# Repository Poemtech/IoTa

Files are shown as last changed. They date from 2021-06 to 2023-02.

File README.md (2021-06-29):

# IoTa
### The IoTa is an open-source cellular developer board featuring the ublox SARA-R410 modem, an ARM Cortex-M0+ and an ARM Cortex-M4.
### IoTa: a complete cellular IoT hardware development platform
### *Features:*
- [NXP ARM Cortex-M0+](https://www.nxp.com/products/processors-and-microcontrollers/arm-microcontrollers/general-purpose-mcus/kl-series-cortex-m0-plus/kinetis-kl1x-48-mhz-mainstream-small-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)
- [NXP ARM Cortex-M4](https://www.nxp.com/products/processors-and-microcontrollers/arm-microcontrollers/general-purpose-mcus/k-series-cortex-m4/k2x-usb/kinetis-k22-120-mhz-cost-effective-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)
- Battery fuel gauge
- LiPo charge control
- LEDs
  -  White
  -  RGB
- 3.3V Power output
- Four Serial Interfaces
  - 2 UART's
  - 1 CAN
  - 1 SPI (with a second optional configuration)
  - 1 I2C (with a second optional configuration)
- 23 GPIO pins
- 19 PWC/DAC channels
- 8 ADC channels
- 10 Wakeup Pins
 ### Efficient Development with the Arduino IDE 
Dual processor design eliminates the need for a host processor. Code development on the user processor using the Arduino IDE enables rapid deployment of your IoT design. 

oshw_facts (1)

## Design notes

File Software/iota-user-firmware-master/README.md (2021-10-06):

# POEM Technology IoTa Arduino Integration
Files necessary to add POEM Technology IoTa board to the Arduino IDE

Needs Arduino IDE version 1.8.0 and up.

## Installation
To set up the Arduino IDE environment for working with the POEM Technology IoTa board, add
https://poemtechnology.com/downloads/iota/arduino_integration/package_iota_index.json
to your Arduino IDE board manager.

## For more information
Example Arduino sketches are available in the [libraries directory](konektdash/libraries)
There are also more example sketches at: https://github.com/hologram-io/hologram-dash-arduino-examples

Questions? Ask a question at: mailto: support@poemtechnology.com

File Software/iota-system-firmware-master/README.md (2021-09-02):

# IoTa System Arduino Core

## Introduction
This is an Arduino implementation for the System processor on the POEM Technology IoTa.
Build your own image using the Arduino IDE or build the included POEM Technology
firmware.

## Arduino Installation

1. Find your local Arduino directory (e.g. macos `~/Documents/Arduino/`).
2. In the `hardware` directory, clone this repository.
3. Open the Arduino IDE (close/reopen if already running).
4. Select the `IoTa System` board from the `system.poemtechnology.com IoTa Boards` section of the board selection menu.

## Building Firmware

1. With the `IoTa System` board selected, from the Examples menu, select an example sketch.
2. Click the Verify button to build.

## Programming the User processor

1. Use Hologram Arduino package version 0.10.4 or later.
2. Open the user sketch to program.
3. From the Programmer select `hologram.io USB loader`.
4. From the Firmware Updates menu, select `Custom Firmware`.
5. Click the Upload button in the Arduino IDE.

## Programming the System processor

1. From the Programmer select `system.poemtechnology.com USB`.
2. Connect the IoTa to your computer via USB.
3. Press the Program button on the IoTa.
4. Click the Upload button in the Arduino IDE.

## Support
Please feel free to [reach out to us](mailto:support@poemtechnology.com) if you have any questions/concerns.

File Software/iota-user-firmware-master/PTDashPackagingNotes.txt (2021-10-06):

Follow the guidance on this page: https://www.hackster.io/wallarug/arduino-ide-creating-custom-boards-89f7a6

Note: To get IIS to serve up JSON, do this: https://blogs.msdn.microsoft.com/africaapps/2013/06/07/how-to-serve-static-json-files-from-a-windows-azure-website/

https://myilevel.com/downloads/dash/arduino_integration//package_poemtechnology_index.json

https://myilevel.com/downloads/dash/arduino_integration/ptdash-0.11.2.zip

Get a SHA256 has of the ZIP file: (Get-FileHash ZIP filename -Algorithm SHA 256).Hash

Get the size of the ZIP file: (Get-Item ZIP).Length

Create Package
--------------
To create a package, run the Create-ArduinoPackage.ps1 -Version <version> from Powershell. Change to the directory
where Create-ArduinoPackage.ps1 is before running as the path defaults are based off of that location.

Deploy Package
--------------
Package hosting on corp site can be managed via SiteGround by copying the contents of the "arduino_integration" folder to the corp site folder
under "/poemtechnology.com/public_html/downloads/iota/arduino_integration".

The contents of the ZIP file are the files/folders below the ptdash directory:
	/cores
	/libraries
	/variants
	boards.txt
	platform.txt
	programmers.txt

Changed VM compiler settings to remove deep search for libraries.

To work on the PT Dash library at the same time as using another verison of the library, create a TFS/VS workspace in
the Arduino documents directory (e.g. C:\Users\<usernmae>\Documents\Arduino\hardware\ptdash-user-firmware-working) and
get and work in that directory. Note: Be sure to select the correct PT Dash version (i.e. look for your working forlder)
before bulding a test harness. Also, the name matters. Make sure it starts with the boards name.

There are name collisions between boards that have the same name. So, The POEM Technology Dash is called the "ptdash" and
the working (i.e. development) version is called "ptdashdev". This mainly impacts the boards.txt file and requires that any
item with the name "ptdashdev" needs to be renamed to "ptdash" as part of the packaging process. Also, a working version of
the PTDash board needs to be installed in order for the programmers to be found by the development environment (as of 
2020-02-10).

PS replacement magic for baords.txt: PS> Get-Content boards.txt | Select-String ptdashdev | % { $_.Line.replace("dev", "").replace("DEV", "").replace("Dev", "") }

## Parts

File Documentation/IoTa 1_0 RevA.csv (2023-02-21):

Comment | Description | Designator | Footprint | LibRef | Quantity | MFG | MPN
ANT-A-1JB | Amphenol | ANT_UFL | UFL | ANT-A-1JB | 1 | Amphenol | A-1JB
1 uF | Capacitor, 1 uF, 0603 | C1 | CAP0603 | CAP1uF_0603 | 1 | MURATA | GRM188R71C105KA12D
0.1 uF | CAPACITOR, 0.1 uF, 0402 | C2, C3, C4, C6, C7, C8, C9, C12, C14, C15, C18, C24, C25, C26, C48 | CAP0402 | CAP0.1uF_0402 | 15 | MURATA | GRM155R61C104KA88D
2.2 uF | Capacitor, 2.2 uF, 0603 | C10, C11, C13, C28 | CAP0603 | CAP2.2uF_0603 | 4 | SAMSUNG | CL10A225MQ8NNNC
1uF | CAPACITOR, 1uF, 0402 | C16, C20, C49 | CAP0402 | CAP1uF_0402 | 3 | AVX | 04026D105KAT2A
10 nF | CAPACITOR, 10 nF, 0402 | C27, C39 | CAP0402 | CAP10nF_0402 | 2 | MURATA | GRM155R71C103KA01D
10 uF | Capacitor, 10 uF, 0603 | C33, C34 | CAP0603 | CAP10uF_0603 | 2 | Murata | GRM188R60J106ME84D
22 uF | Capacitor, 22 uF, 0603 | C36, C37, C38 | CAP0603 | CAP22uF_0603 | 3 | MURATA | GRM188R60J226MEA0D
56 pf | CAPACITOR, 56 pF, 0402 | C40 | CAP0402 | CAP56pF_0402 | 1 | KEMET | C0402C560J5GACTU
47 pF | CAPACITOR, 47 pF, 0402 | C41, C42, C43, C44, C45 | CAP0402 | CAP47pf_0402 | 5 | AVX | 04025A470JAT2A
15 pf | CAPACITOR, 15 pF, 0402 | C46 | CAP0402 | CAP15pF_0402 | 1 | AVX/ELCO | 04025A150JAT2A
330uF | Capacitor, 330 uF, 1210, Polarized Tantalum | C47 | CAP1210POL | CAP330uF_1210P | 1 | AVX | F950J337MBAAQ2
LED_0402_VLMW | LED, Vishay White 0402 | D1, D7 | LED_0402_VISHAY_VLMW | LED_0402_VLMW | 2 | VISHAY | VLMW1500-GS08
 | DIODE,ZENER VOLTAGE SUPPRESSOR,+/-14V | D3, D4, D5, D6, D9, D10, D11 | PESD_0402 | PESD_14V | 7 | Littlefuse | PESD0402-140
CDBQR0230L | Schottky Barrier Diode, 200 mA, 30 V, 0402 package | D8 | DIODE_0402 | DIODE_0402_200mA | 1 | Comchip | CDBQR0230L
3A | Fuse, 3A, 0603 | F6 | RES0603 | FUSE_0603 | 1 | Bourns | SF-0603S300-2
Micro USB B FCI 10118193 | Connector, Micro USB B, FCI | J1 | USB_MICRO_FCI_10118193 | USB_MICRO_B_FCI_10118193 | 1 | Amphenol FCI | 10118193-0001LF
BAT_TERM_TOP_ENTRY | Battery Connector JST-PH2 Top Entry | J20 | JST-PH-2-Top | BAT_TERM_TOP_ENTRY | 1 | JST | B2B-PH-SM4-TB(LF)(SN)
22-28-4180 | Header, Male, 1x18, 0.1" | JLEFT, JRIGHT | 1X18 | PINHD-1X18 | 2 | MOLEX | 22-28-4180
FerriteBead_220ohm | FerriteBead, 220ohm | L1, L2, L3, L7 | RES0603 | FerriteBead_220ohm | 4 | Murata | BLM18AG121SN1D
1uH | Inductor, 1 uH, Coilcraft | L5 | COILCRAFT_XFL4020 | INDUCTOR_1UH_XFL4020-102MEC | 1 | Coilcraft | XFL4020-102MEC
22 | Resistor, 22 ohm, 0402 case, 1% | R1, R2 | RES0402 | RES22R_0402 | 2 | YAEGO | RC0402FR-0722RL
62k | Resistor, 62K ohm, 0402 case | R7 | RES0402 | RES62K_0402_1 | 1 | YAEGO | RC0402FR-0762KL
2k | Resistor, 2K ohm, 0402 case | R8 | RES0402 | RES2K_0402 | 1 | YAEGO | RC0402FR-072KL
150k | Res, 150k ohm, 0402 case, 1% | R12 | RES0402 | RES150K_0402 | 1 | YAEGO | RC0402FR-07150KL
1M | Resistor, 1M ohm, 0402 case, 1% | R13 | RES0402 | RES1M_0402 | 1 | YAEGO | RC0402FR-071ML
470 | Resistor, 470 ohm, 0402 case, 1% | R19, R20 | RES0402 | RES470R_0402 | 2 | PANASONIC | ERJ-2GEJ471X
120 | Resistor, 120 ohm, 0402 case, 1% | R21 | RES0402 | RES120R_0402 | 1 | PANASONIC | ERJ-2GEJ121X
160 | Resistor, 160 ohm, 0402 case, 1% | R22 | RES0402 | RES160R_0402 | 1 | PANASONIC | ERJ-2GEJ161X
10K | Resistor, 10k ohm, 0402 | R24, R35, R36, R37, R38, R40, R47, R2000 | RES0402 | RES10K_0402 | 8 | YAEGO | RC0402JR-0710KL
75 | Resistor, 75 ohm, 0402, 1% | R26, R65 | RES0402 | RES75R_0402 | 2 | YAEGO | RC0402FR-0775RL
1k | Resistor, 1k, 0402 case, 1% | R45 | RES0402 | RES1K_0402 | 1 | YAEGO | RC0402JR-071KL
CRCW08050000Z0EA |  | R51 | RESC2013X50X30LL20T20 | CMP-2001-04896-1 | 1
0 | Resistor, 0 ohm, 0402 | R66 | RES0402 | RES0R_0402 | 1 | PANASONIC | ERJ-2GE0R00X
SIM_CARD_NANO | Connector, SIM Card,Nano | SIM1 | SIM_CARD_NANO | SIM_CARD_NANO | 1 | GLOBAL CONNECTOR TECHNOLOGY | SIM8050-6-0-14-01-A
LED_RGB_1mm_sq | LED, Tri-color, RGB, 1mm sq | smlp | LED-RGB-1X1 | LED_RGB_1mm_sq | 1 | Rohm | SMLP34RGB1W3
SWITCH_PTS810 | Switch, C&K, PTS810 | SW1, SW2 | SWITCH_PTS810 | SWITCH_PTS810 | 2 | C&K Components | PTS810 SJM 250 SMTR LFS
MICROCHIP_73871 | Stand-alone Load Sharing and LiPo Battery Charge management controller | U1 | QFN50P400X400X80_20_pin | MICROCHIP_73871 | 1 | MICROCHIP | MCP73871-2CCI/ML
TPS63020 | Regulator, Boost Buck, Adjustable, 3A | U2 | QFN-14-POWERPAD3X4DSJ | TPS63020 | 1 | TI | TPS63020DSJ
CDBQR0230L | Schottky Barrier Diode, 1.5 A, 30 V, 0402 package | U3, U4 | SODFL350X99-2N | DIODE_SOD123F_1A | 2 | Toshiba Semiconductor and Storage | CRS08(TE85L,Q,M)
MK22FN1M0VLH12 | ARM® Cortex®-M4 Kinetis K20 Microcontroller IC 32-Bit 120MHz 1MB (1M x 8) FLASH 64-LQFP (10x10) | U5 | LQFP-64N | MK22FN1M0VLH12 | 1 | Freescale | MK22FN1M0AVLH12
FREESCALE_MKL17Z256VFM4 | Microprocessor, Freescale, MKL17Z256VFM4 | U6 | QFN50P50 | FREESCALE_MKL17Z256VFM4 | 1 | FREESCALE | MKL17Z256VFM4
VOLTAGE_TRANSLATOR_4_BIT | IC, Voltage Translator, 4-bit | U8 | UQFN_16 | VOLTAGE_TRANSLATOR_4_BIT | 1 | TI | SN74AVC4T774RSVR
 | IC, Current-limited Load Switch, Active High | U9 | SC70-5 | TPS22945 | 1 | Texas Instruments | TPS22945DCKR
 | IC Regulator, LDO 3.3V 0.5A, 4XDFN | U10 | REG_NCP160AMX180TBG | NCP177-D | 1 | On Semi | NCP177AMX330TCG
SARA-R410 | LTE module for multi-regional use; Cat M1/NB1 deployed bands: 1*, 2, 3, 4, 5, 8, 12, 13, 18, 19, 20, 25, 26*, 28 (* roaming bands) | U16 | SARA | SARA-R410M-02B | 1 | U-BLOX | SARA-R410M-02B
MAX1704X | MAX17043/MAX17044: Battery Fuel Guage (43 is 1cell, 44 is 2cell) | U19 | TDFN-8 | MAX1704X | 1 | Maxim | MAX17043G+U
CRYSTAL_16MHz | Crystal SMD, 16 MHz | X1 | CRYSTAL-SMD-2X1.6 | CRYSTAL_16MHz | 1 | AVX | CX2016DB16000D0WZRC1
32.768 kHz | 32.768kHz ±20ppm Crystal 12.5pF 90 kOhm -40°C ~ 85°C Surface Mount 2-SMD | X2, X3 | CRYSTAL_ABS05 | CRYSTAL_32.768K_ABS05 | 2 | Abracon | ABS05-32.768KHZ-T

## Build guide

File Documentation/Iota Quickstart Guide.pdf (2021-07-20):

# POEM IoTa Quickstart Guide

## Instructions for Running Serial Port Commands

## (NOTE: This document is derived from the documentation for the Hologram DASH. References to the DASH as a module as now replaced by IoTa, but software names will still contain

the legacy “dash” nomenclature. (e.g. “dash_repl_basic”).

### Contents

I. SIM Card Management
-Inserting SIM Card
-Creating a Hologram Account -Activating SIM Card
II. | IoTa Setup
III. | REPL Program -Installing the Arduino IDE -Uploading dash_repl_basic -Connecting the IoTa
IV. | Commands -Cloud Connect -LED -Clock
V. Messages

I. SIM Card Management

Inserting SIM Card:

To properly insert your SIM card, pop it out of the carrier card and insert it into the back of the IoTa in the small silver compartment that is the same size as the SIM. There is a small image of the SIM card next to the compartment that details the orientation it should be inserted.

Orienting SIM Card:

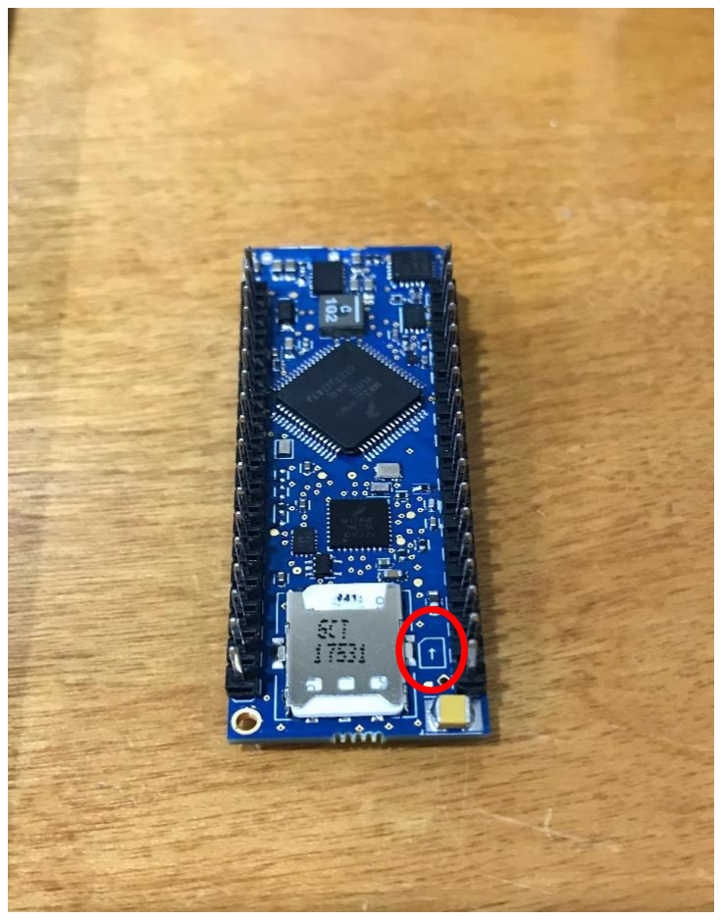
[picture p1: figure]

Creating a Hologram Account:

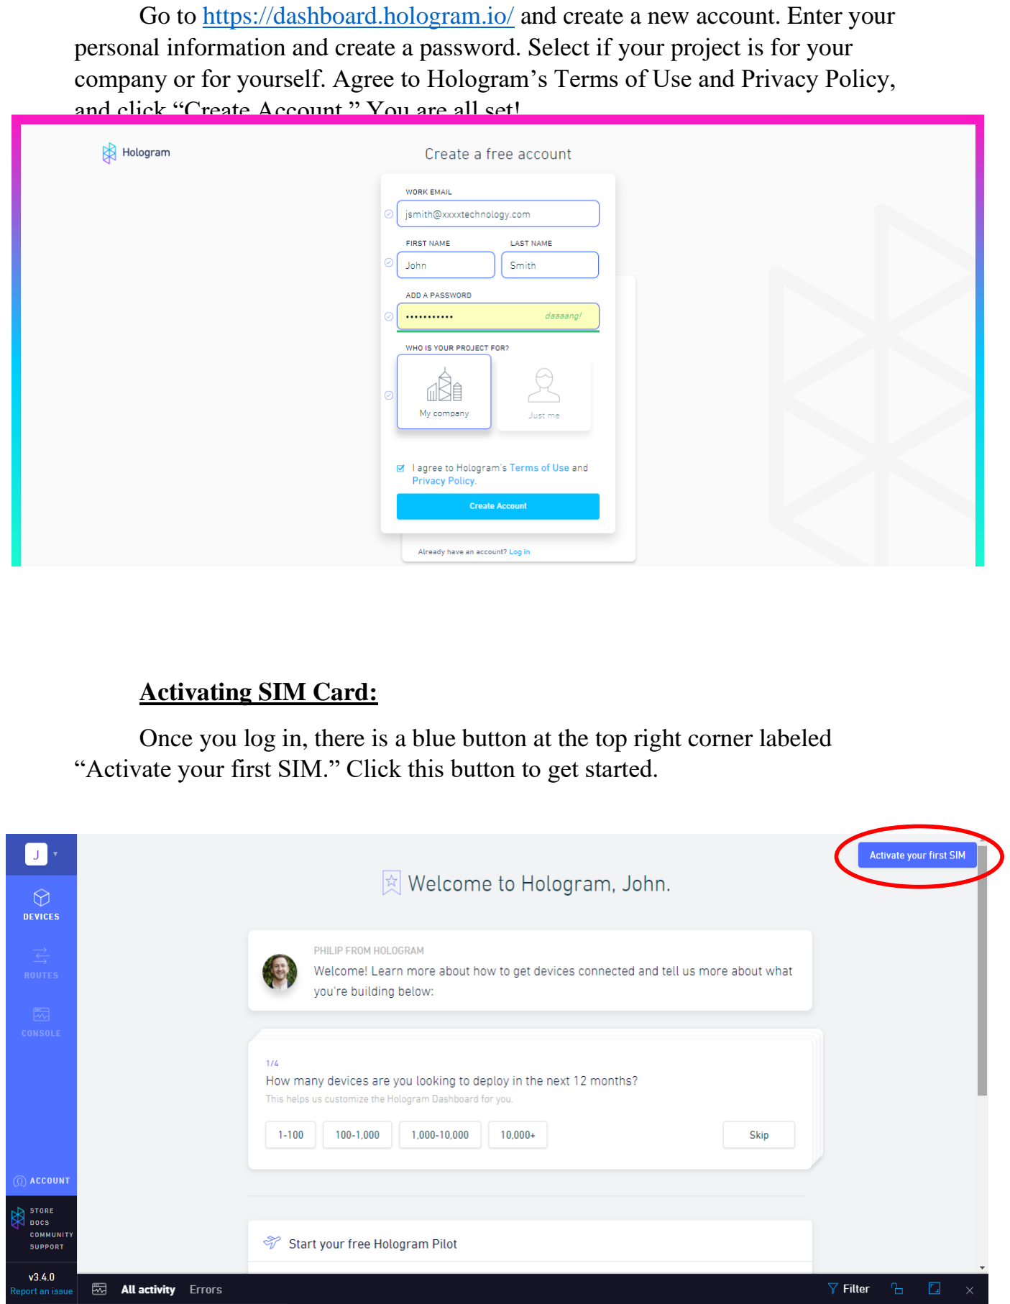
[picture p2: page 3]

Go to https://dashboard.hologram.io/ and create a new account. Enter your personal information and create a password. Select if your project is for your company or for yourself. Agree to Hologram’s Terms of Use and Privacy Policy, and click “Create Account.” You are all set!

Activating SIM Card:

Once you log in, there is a blue button at the top right corner labeled “Activate your first SIM.” Click this button to get started.

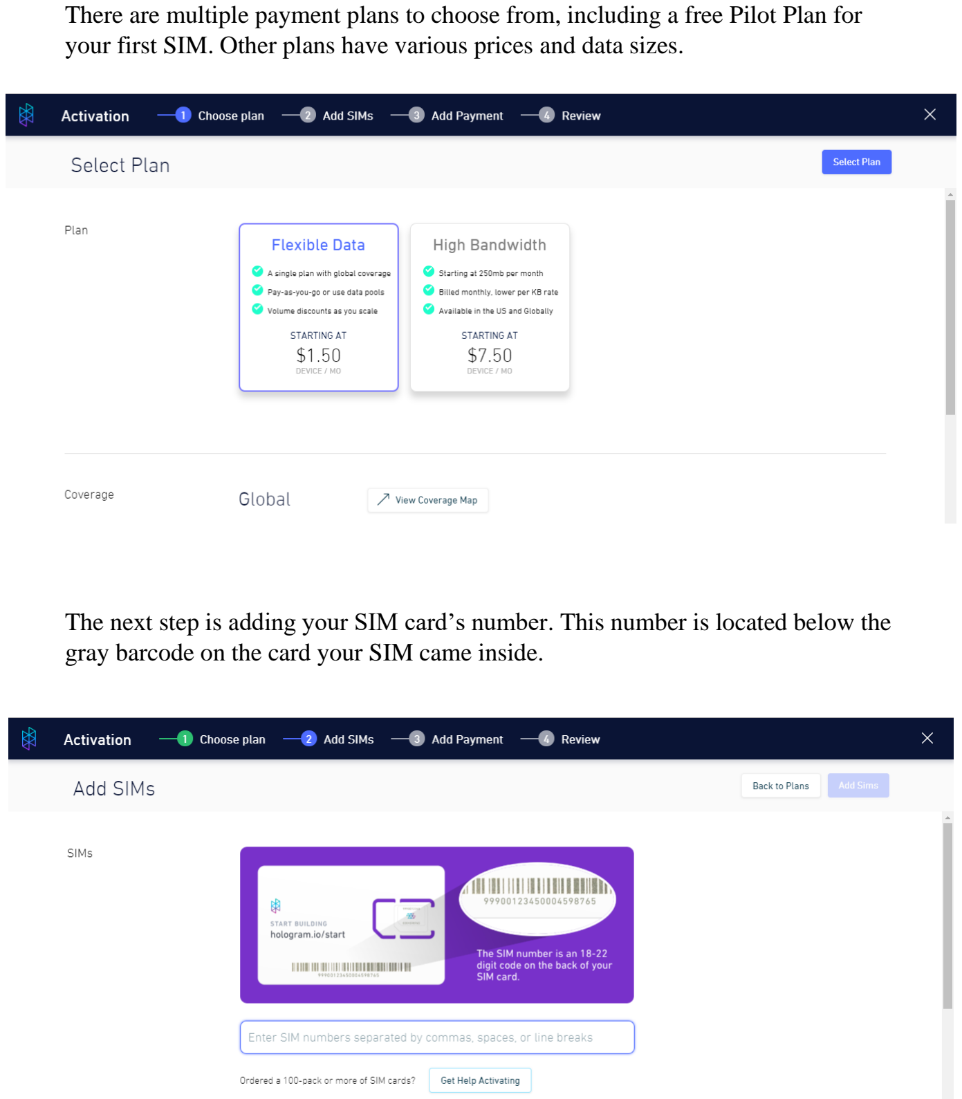
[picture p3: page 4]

There are multiple payment plans to choose from, including a free Pilot Plan for your first SIM. Other plans have various prices and data sizes.

The next step is adding your SIM card’s number. This number is located below the gray barcode on the card your SIM came inside.

You have the option of customizing your SIM’s name, or giving it a tag for future reference.

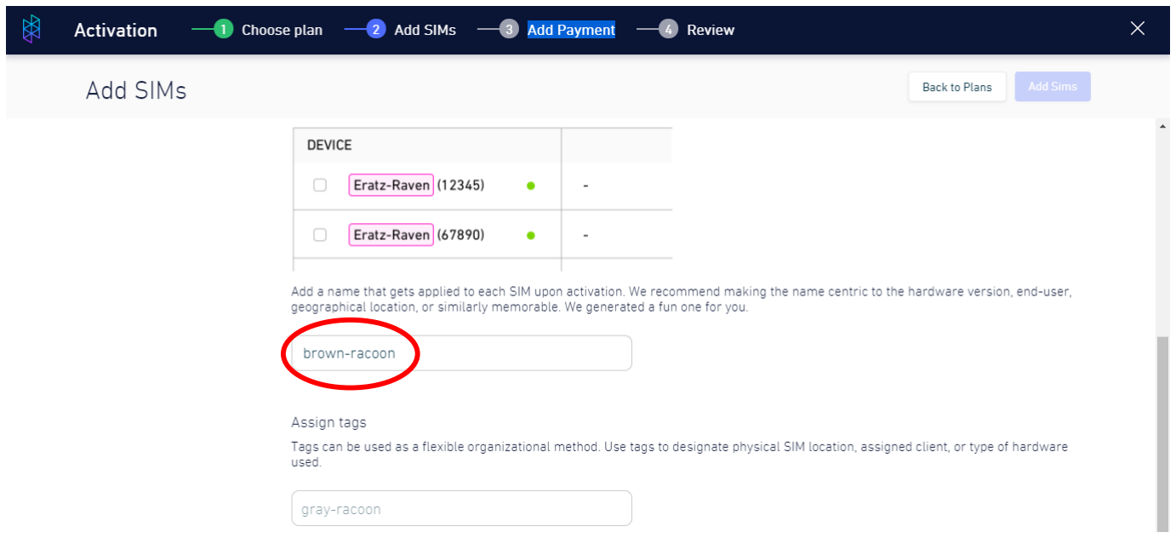
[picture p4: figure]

Enter your payment info. You can review your information before confirming your order. Congrats! You have activated your first SIM card.

II. | IoTa Setup
| Plug the supplied USB cable onto the IoTa and then into a port on your computer.

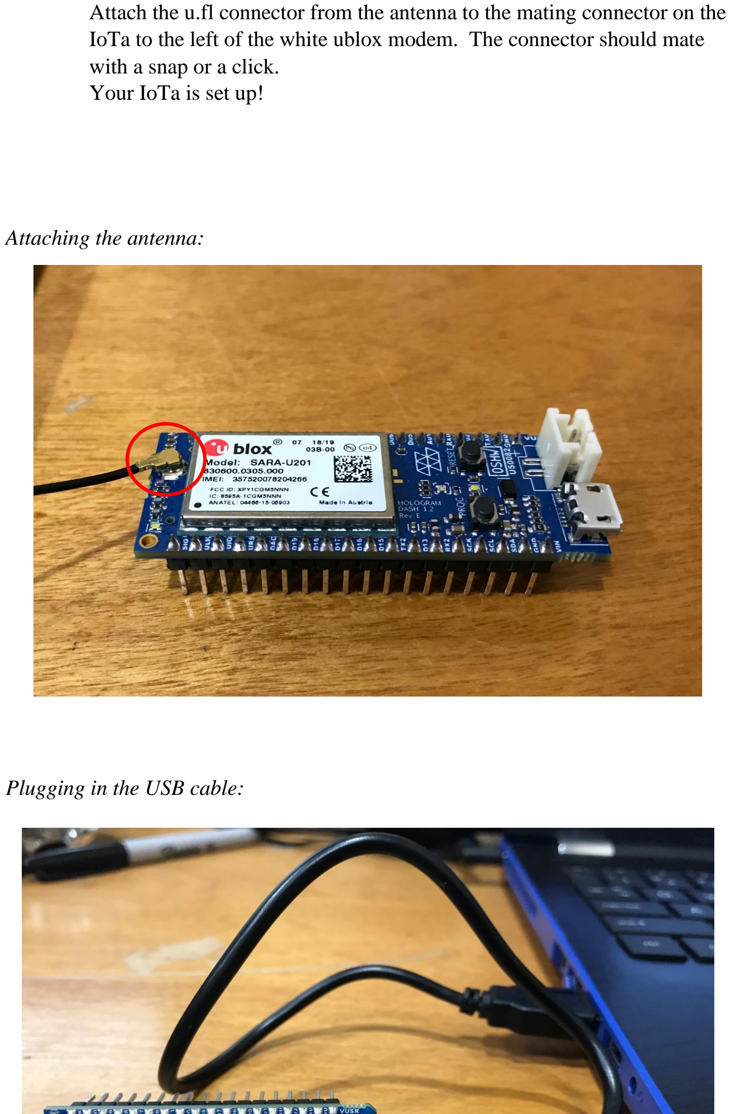
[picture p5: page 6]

Attach the u.fl connector from the antenna to the mating connector on the IoTa to the left of the white ublox modem. The connector should mate with a snap or a click.
Your IoTa is set up!

Attaching the antenna:

Plugging in the USB cable:

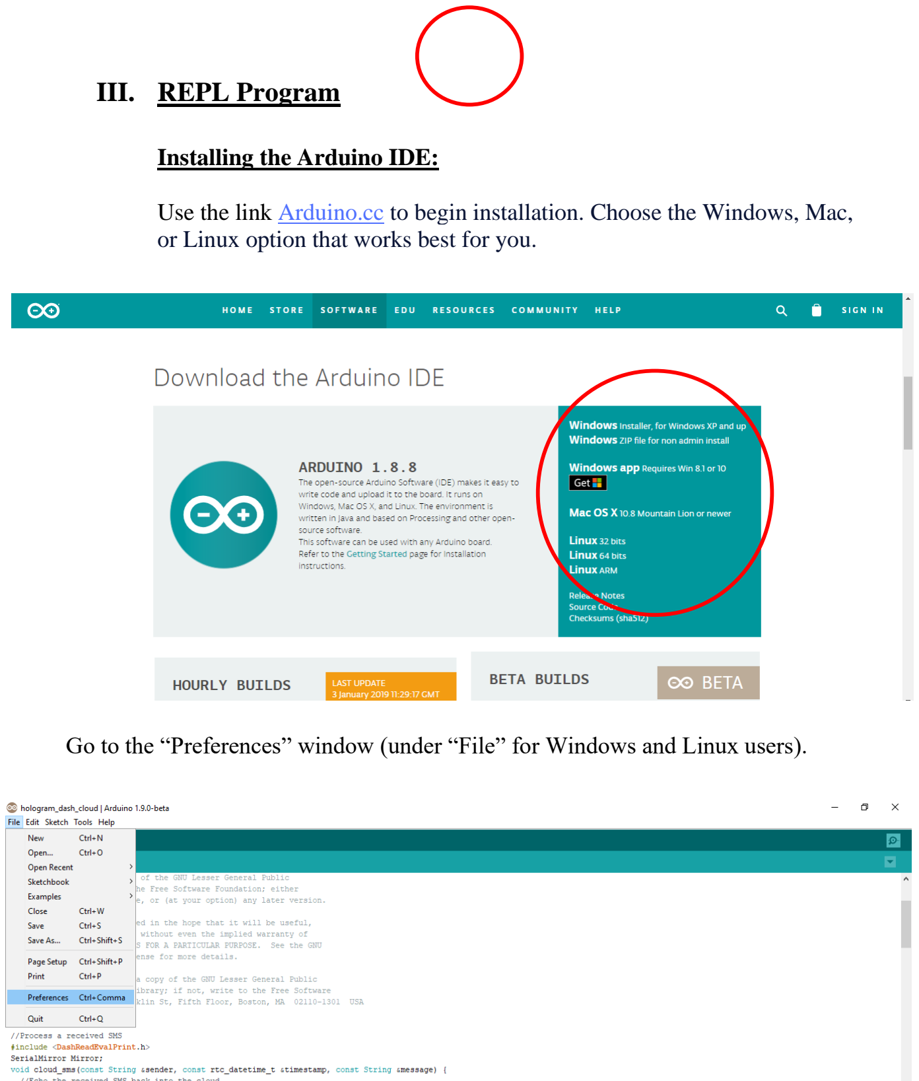
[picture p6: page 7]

III. REPL Program

Installing the Arduino IDE:

Use the link Arduino.cc (https://www.arduino.cc/en/Main/Software) to begin installation. Choose the Windows, Mac, or Linux option that works best for you.

Go to the “Preferences” window (under “File” for Windows and Linux users).

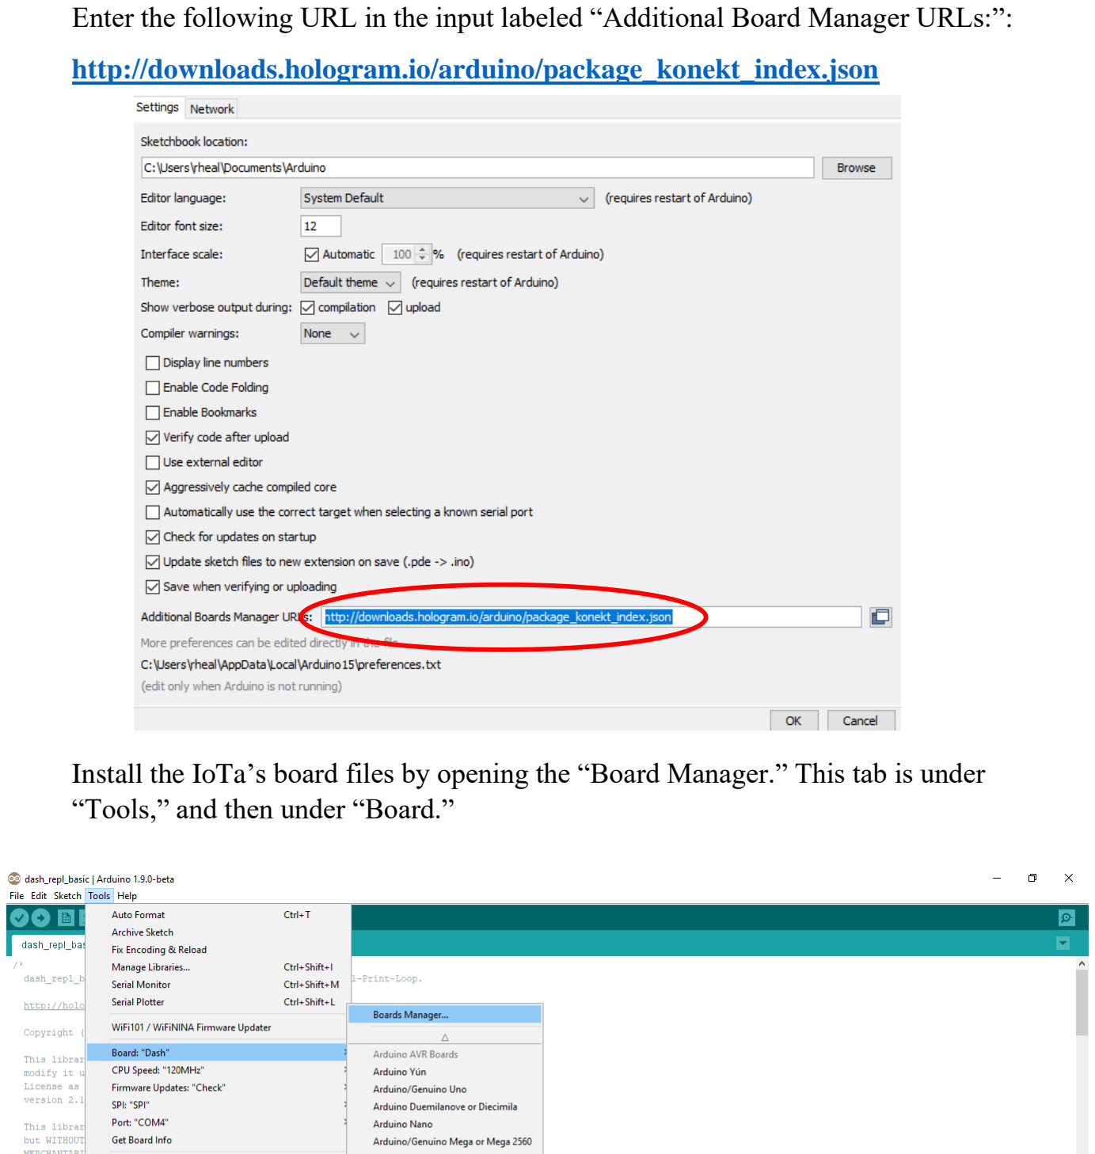
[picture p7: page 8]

Enter the following URL in the input labeled “Additional Board Manager URLs:”:

http://downloads.hologram.io/arduino/package_konekt_index.json

Install the IoTa’s board files by opening the “Board Manager.” This tab is under “Tools,” and then under “Board.”

Choose the “Contributed” option in the “Type” drop down menu. Then, select “Konekt Dash/Dash Pro Boards.” Click “Install” and close the Boards Manager when installation is finished.

Confirm you have the latest version of the IoTa libraries by going to “Boards Manager” again (“Tools” → “Board” → “Board Manager”). Click “Updateable” in the “Type” dropdown menu and if the list contains “Hologram Dash,” update to the most recent version.

Uploading dash_repl_basic:

Go to “File,” “Examples,” and “DashReadEvalPrint.” There is a program called “dash_repl_basic” in this tab, and this program will let you send commands directly to the IoTa. Open this program.

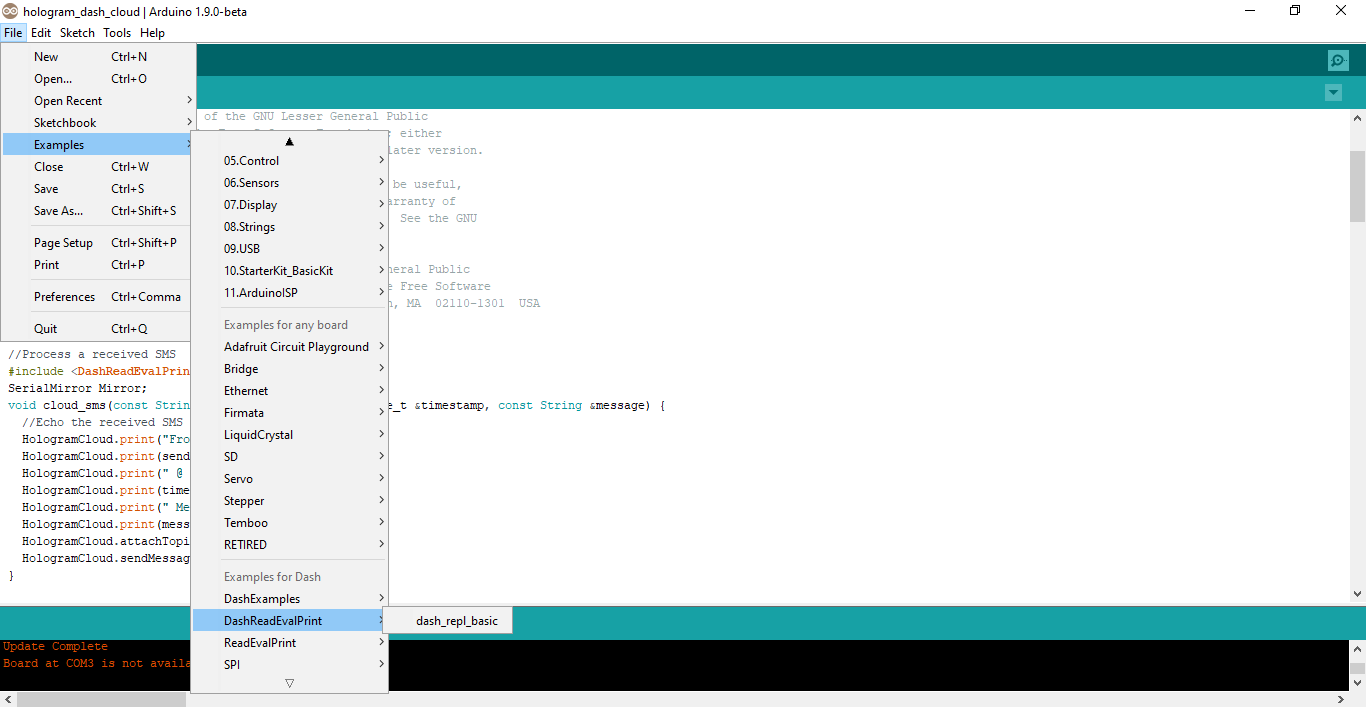
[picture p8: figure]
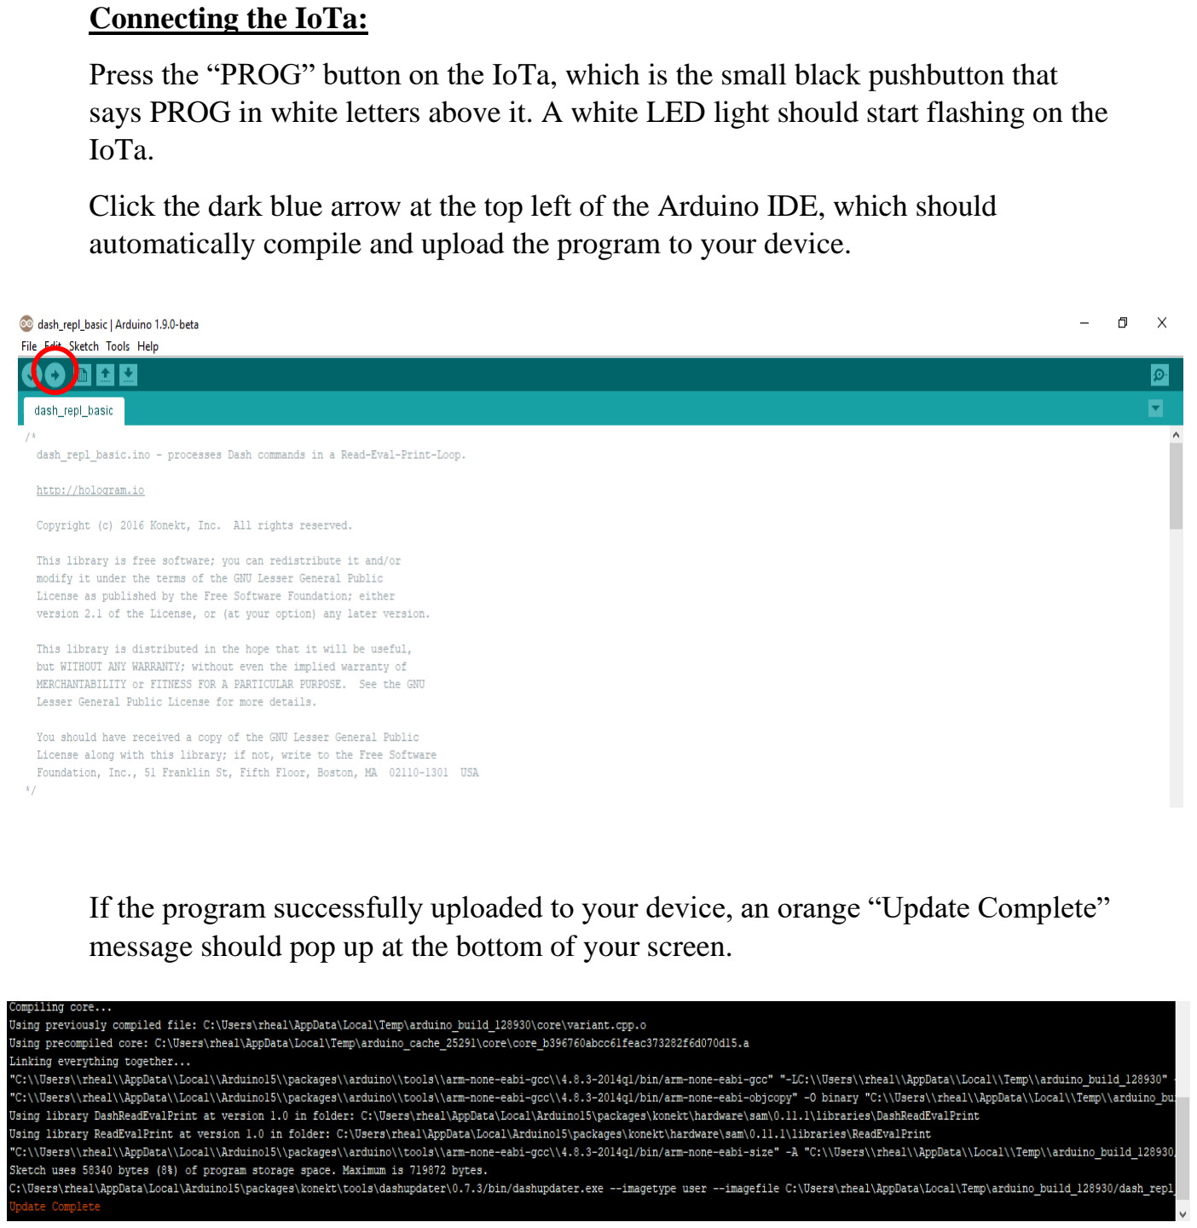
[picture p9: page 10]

Connecting the IoTa:

Press the “PROG” button on the IoTa, which is the small black pushbutton that says PROG in white letters above it. A white LED light should start flashing on the IoTa.

Click the dark blue arrow at the top left of the Arduino IDE, which should automatically compile and upload the program to your device.

If the program successfully uploaded to your device, an orange “Update Complete” message should pop up at the bottom of your screen.

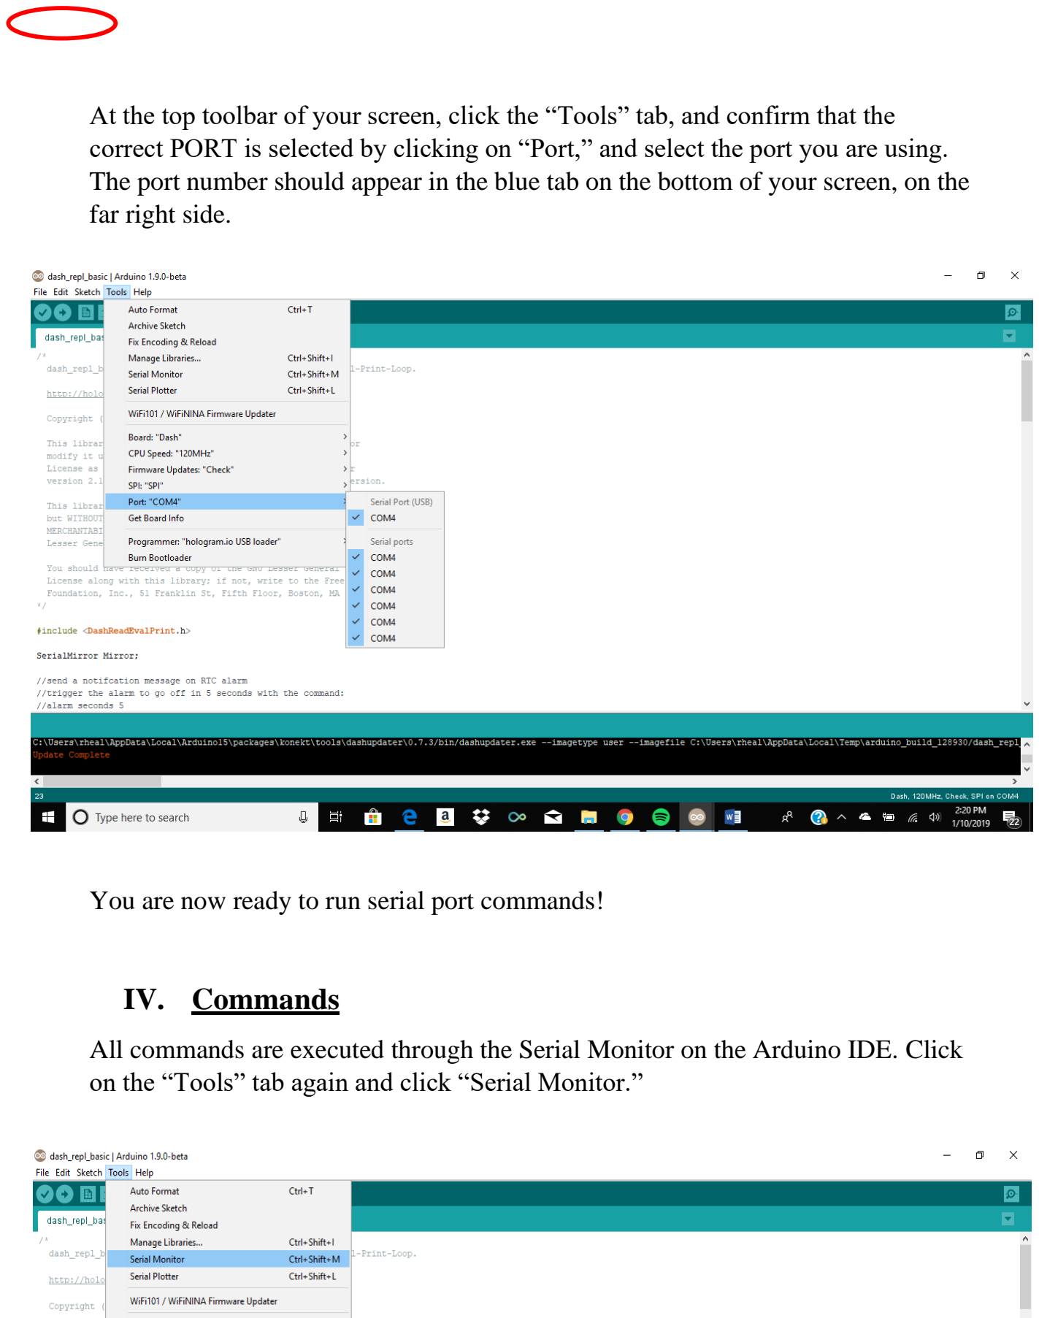
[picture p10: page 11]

At the top toolbar of your screen, click the “Tools” tab, and confirm that the correct PORT is selected by clicking on “Port,” and select the port you are using. The port number should appear in the blue tab on the bottom of your screen, on the far right side.

You are now ready to run serial port commands!

IV. Commands

All commands are executed through the Serial Monitor on the Arduino IDE. Click on the “Tools” tab again and click “Serial Monitor.”

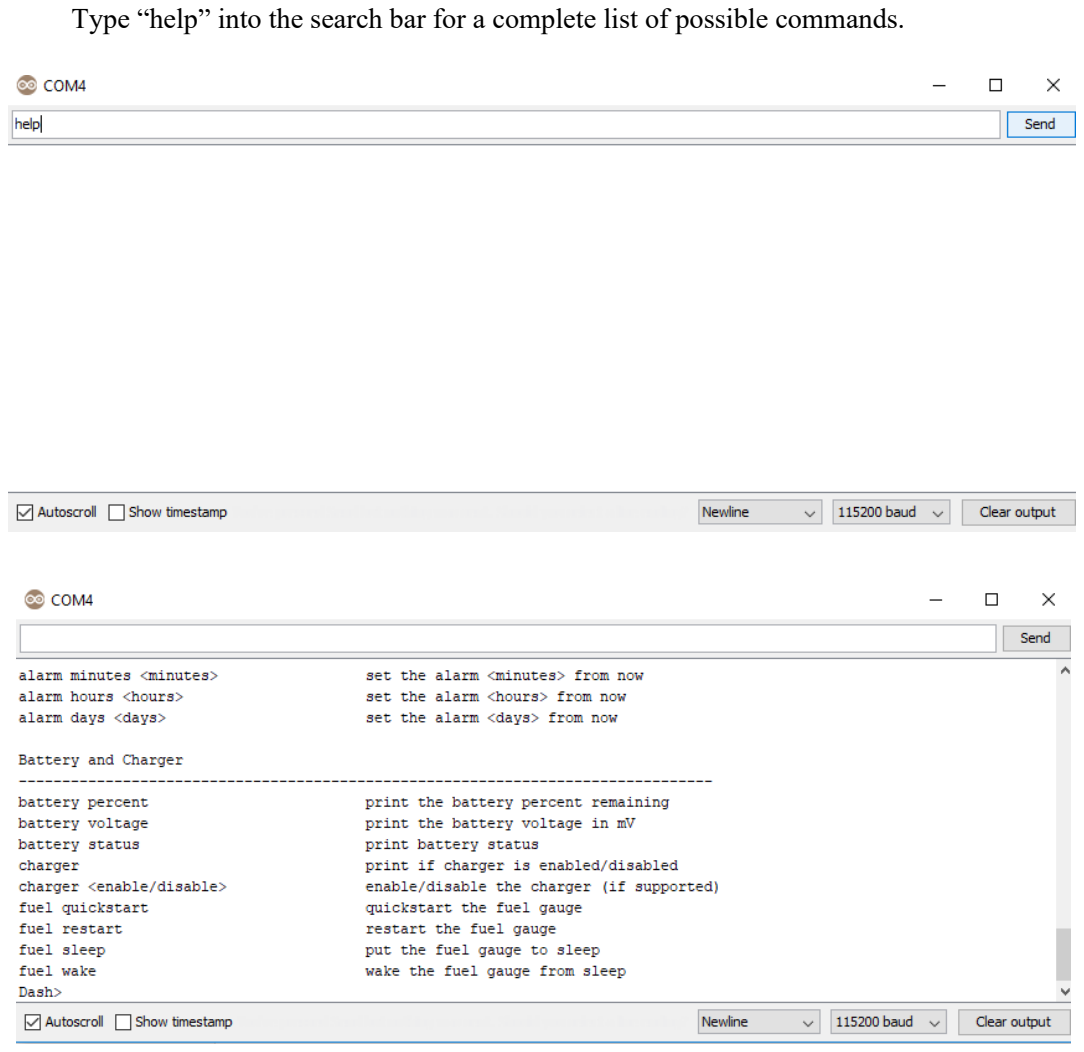
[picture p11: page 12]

Type “help” into the search bar for a complete list of possible commands.

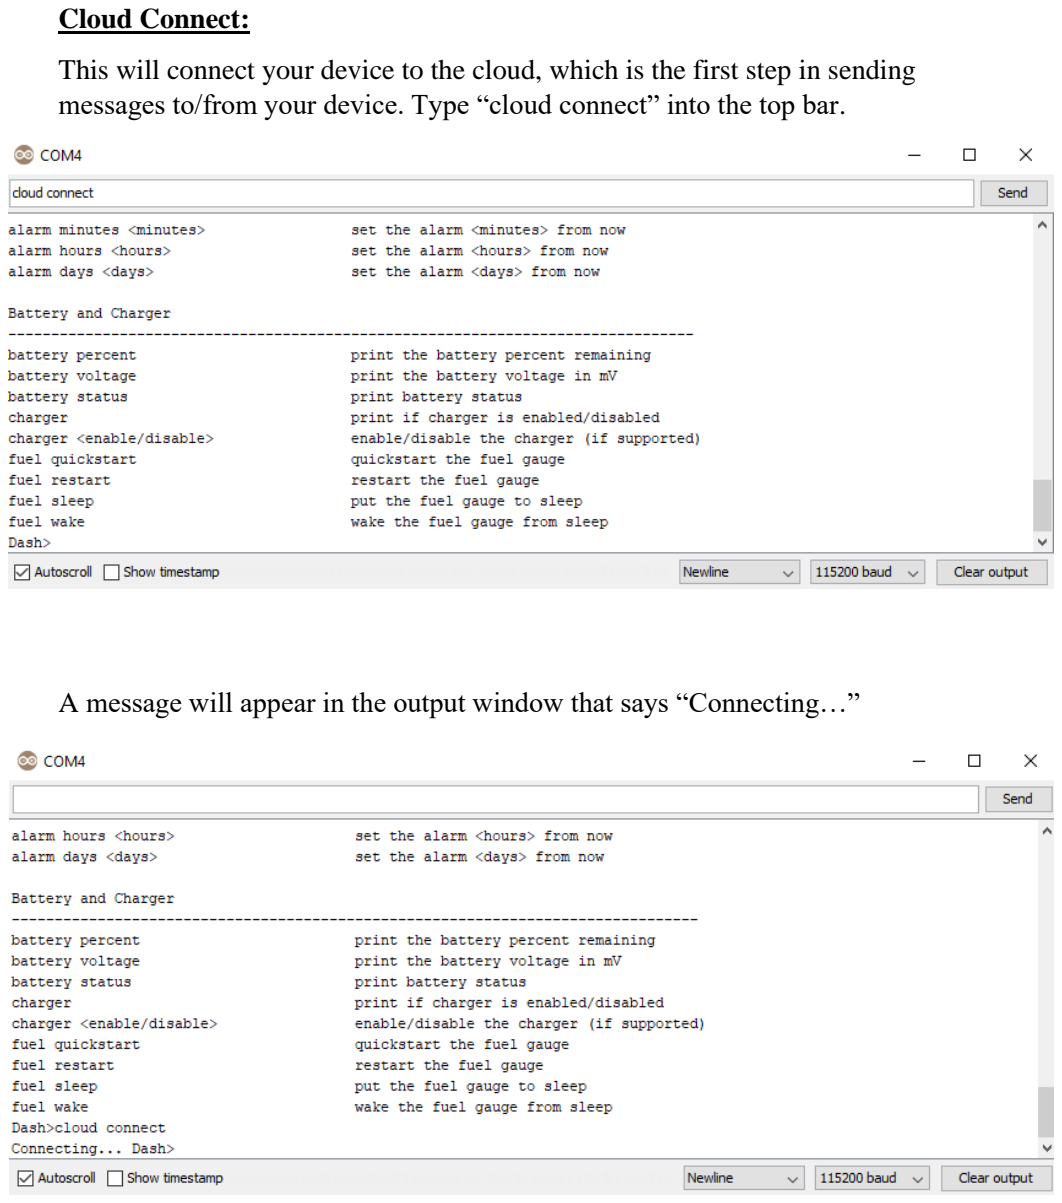
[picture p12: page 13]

Cloud Connect:

This will connect your device to the cloud, which is the first step in sending messages to/from your device. Type “cloud connect” into the top bar.

A message will appear in the output window that says “Connecting…”

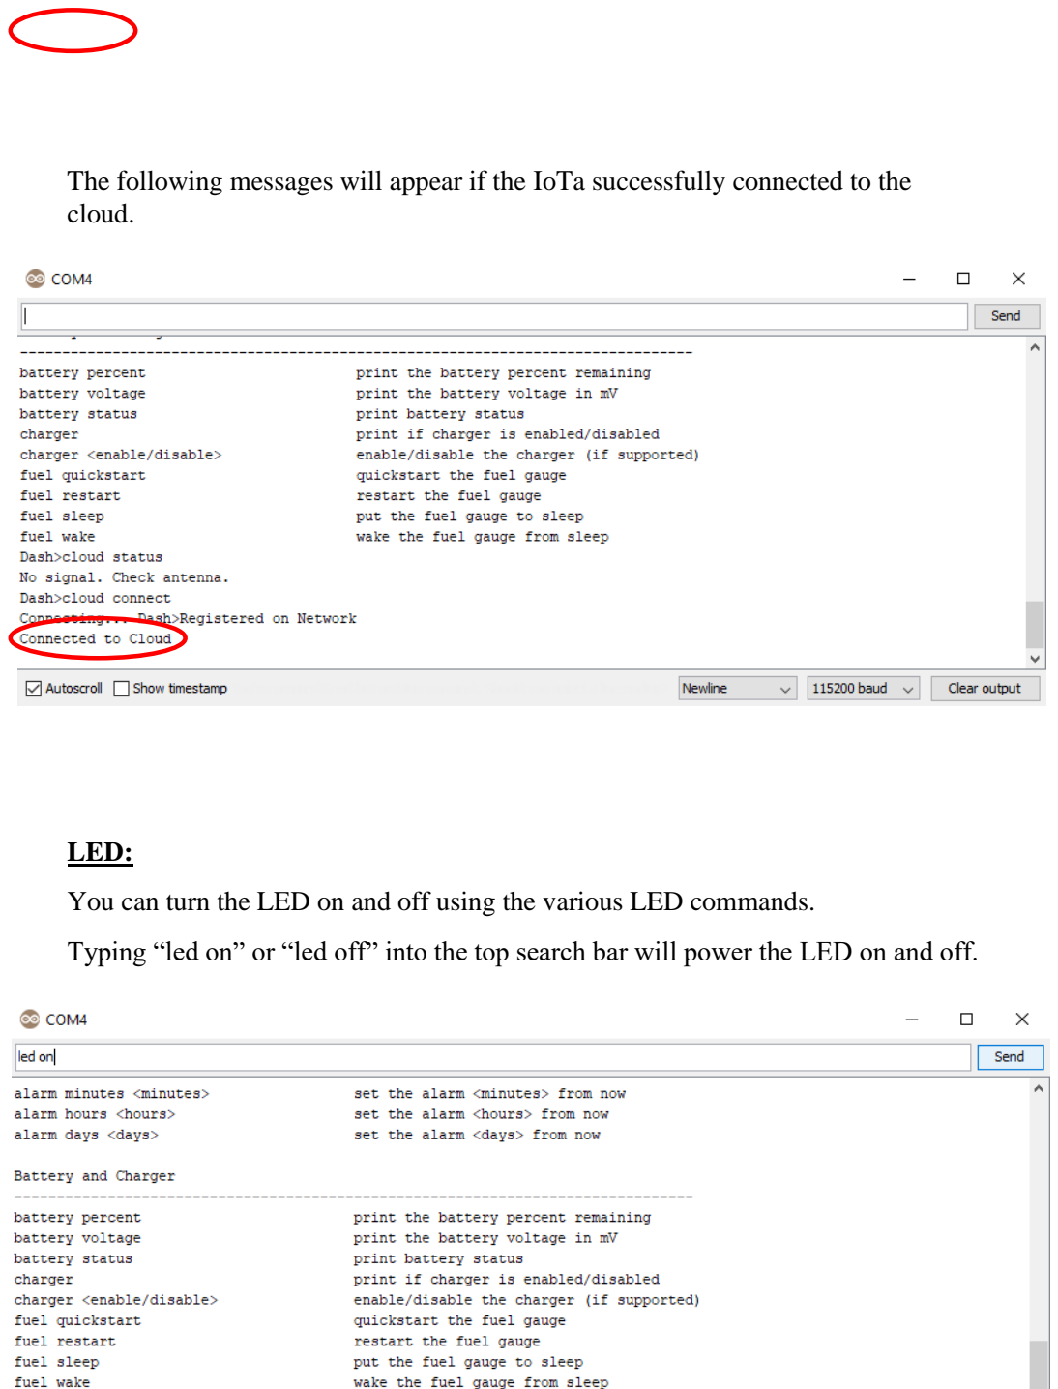
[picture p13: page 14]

The following messages will appear if the IoTa successfully connected to the cloud.

LED:

You can turn the LED on and off using the various LED commands.

Typing “led on” or “led off” into the top search bar will power the LED on and off.

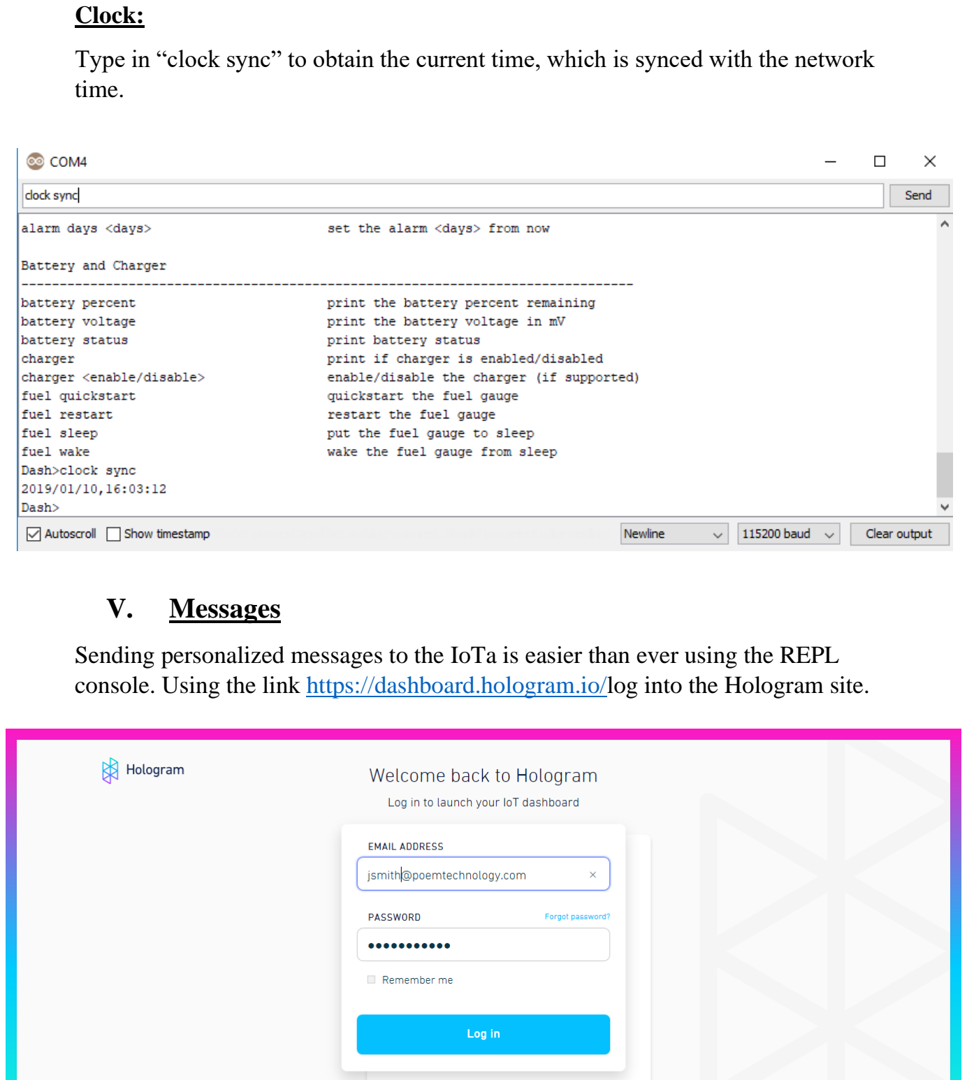
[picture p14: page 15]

Clock:

Type in “clock sync” to obtain the current time, which is synced with the network time.

V. Messages

Sending personalized messages to the IoTa is easier than ever using the REPL console. Using the link https://dashboard.hologram.io/log into the Hologram site.

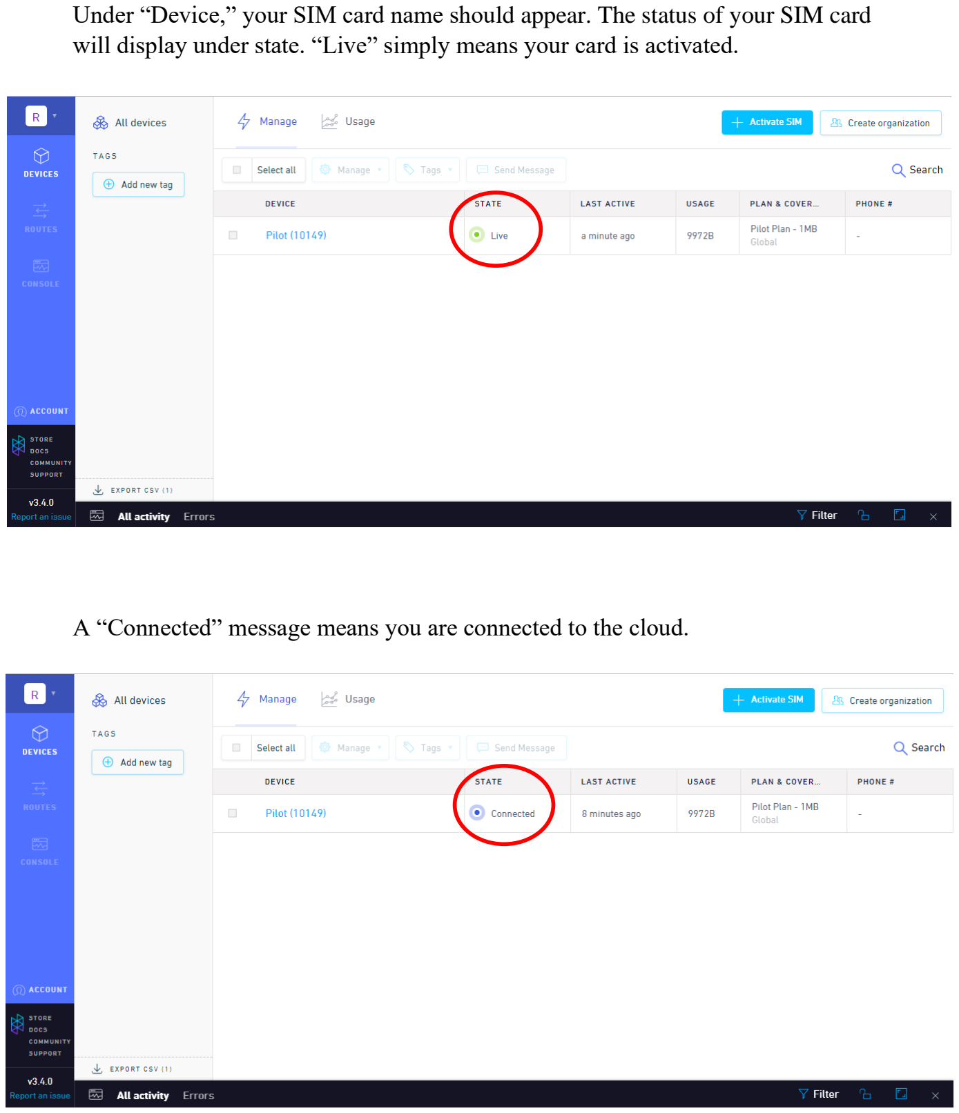
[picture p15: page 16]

Under “Device,” your SIM card name should appear. The status of your SIM card will display under state. “Live” simply means your card is activated.

A “Connected” message means you are connected to the cloud.

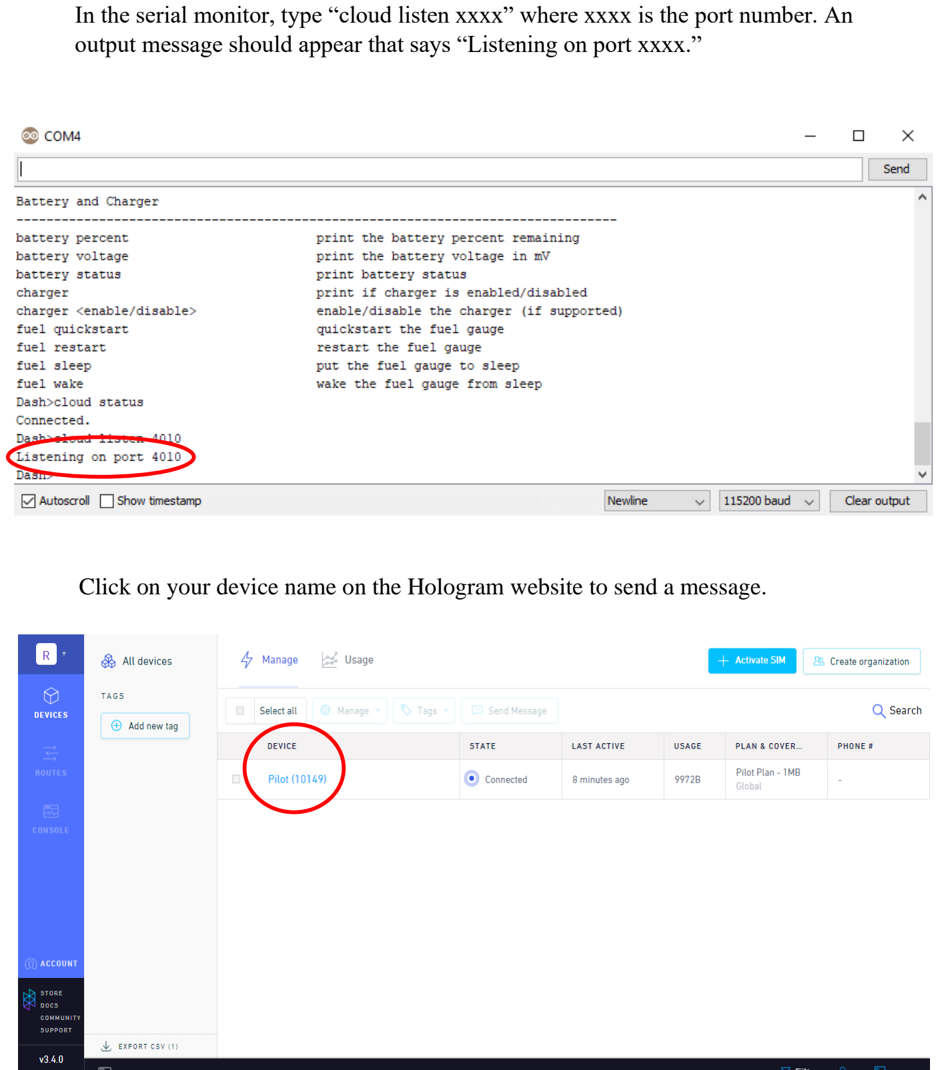
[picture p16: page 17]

In the serial monitor, type “cloud listen xxxx” where xxxx is the port number. An output message should appear that says “Listening on port xxxx.”

Click on your device name on the Hologram website to send a message.

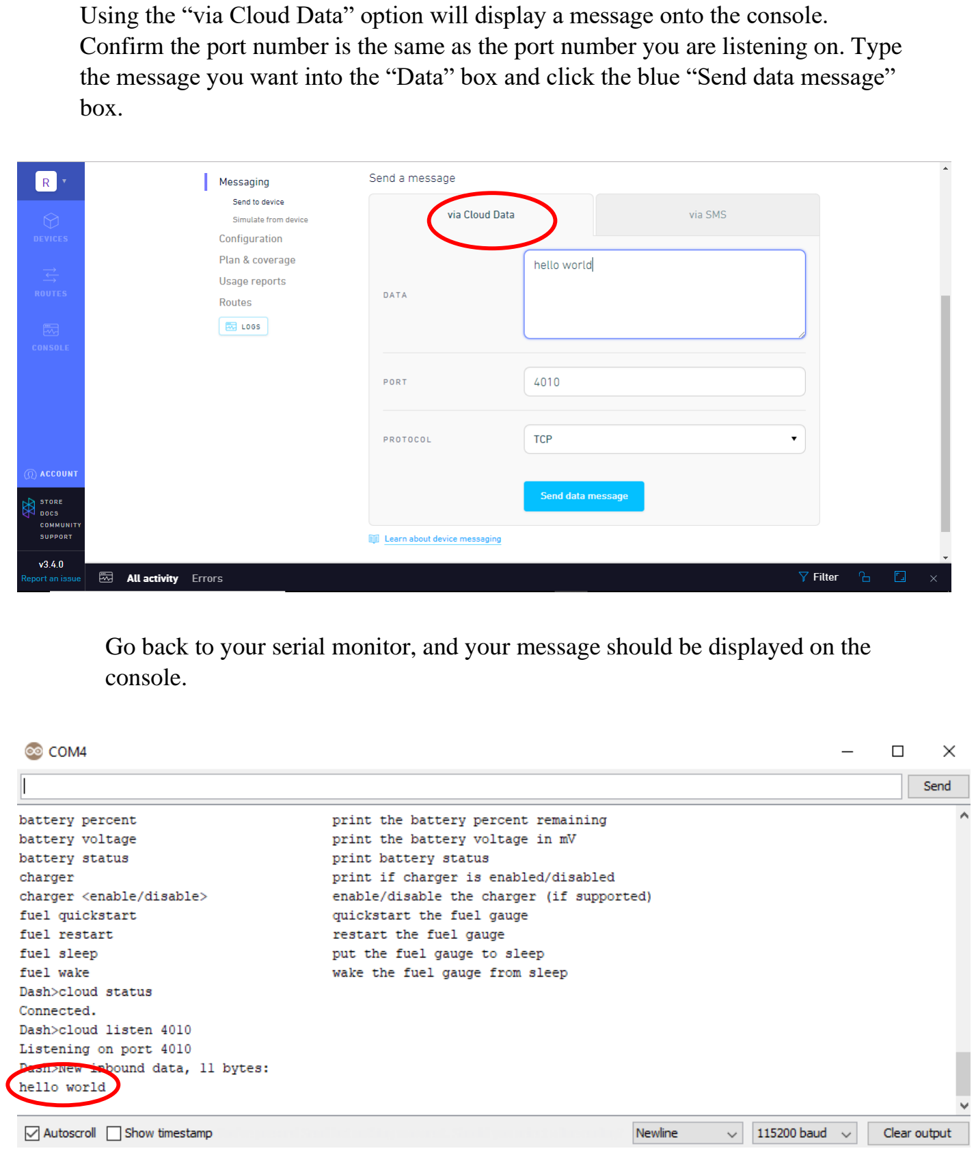
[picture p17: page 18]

Using the “via Cloud Data” option will display a message onto the console. Confirm the port number is the same as the port number you are listening on. Type the message you want into the “Data” box and click the blue “Send data message” box.

Go back to your serial monitor, and your message should be displayed on the console.

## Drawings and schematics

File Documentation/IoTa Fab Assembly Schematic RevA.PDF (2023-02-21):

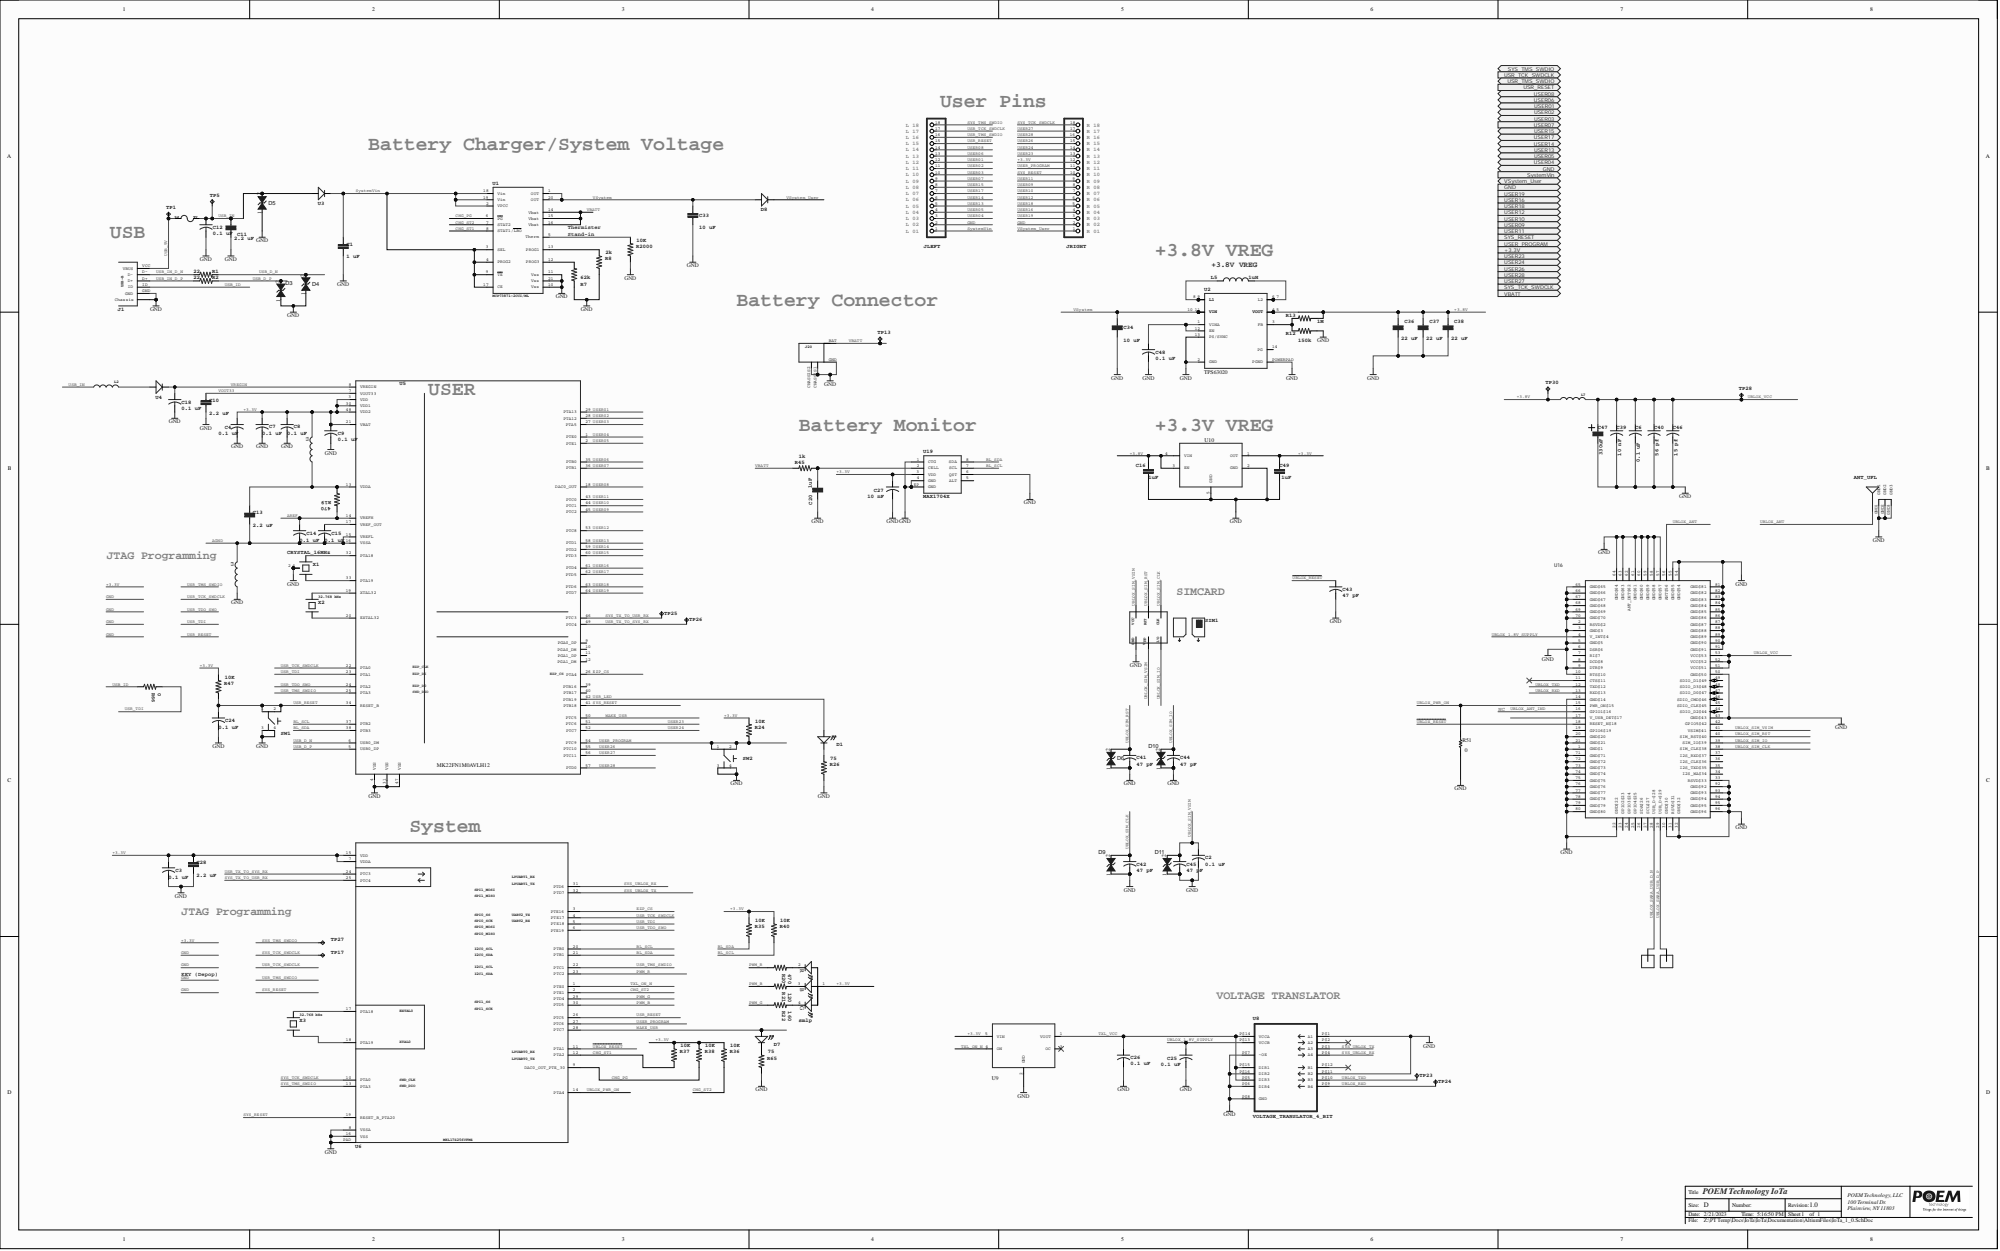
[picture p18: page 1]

Battery Charger/System Voltage

6 6 | 8 2
6 7 | | 8 3

6 8 | | 8 4
6 9 | | 8 5
7 0 | | 8 6

7 6 | 9 2
7 7 | 9 3
7 8 | 9 4
7 9 | 9 5

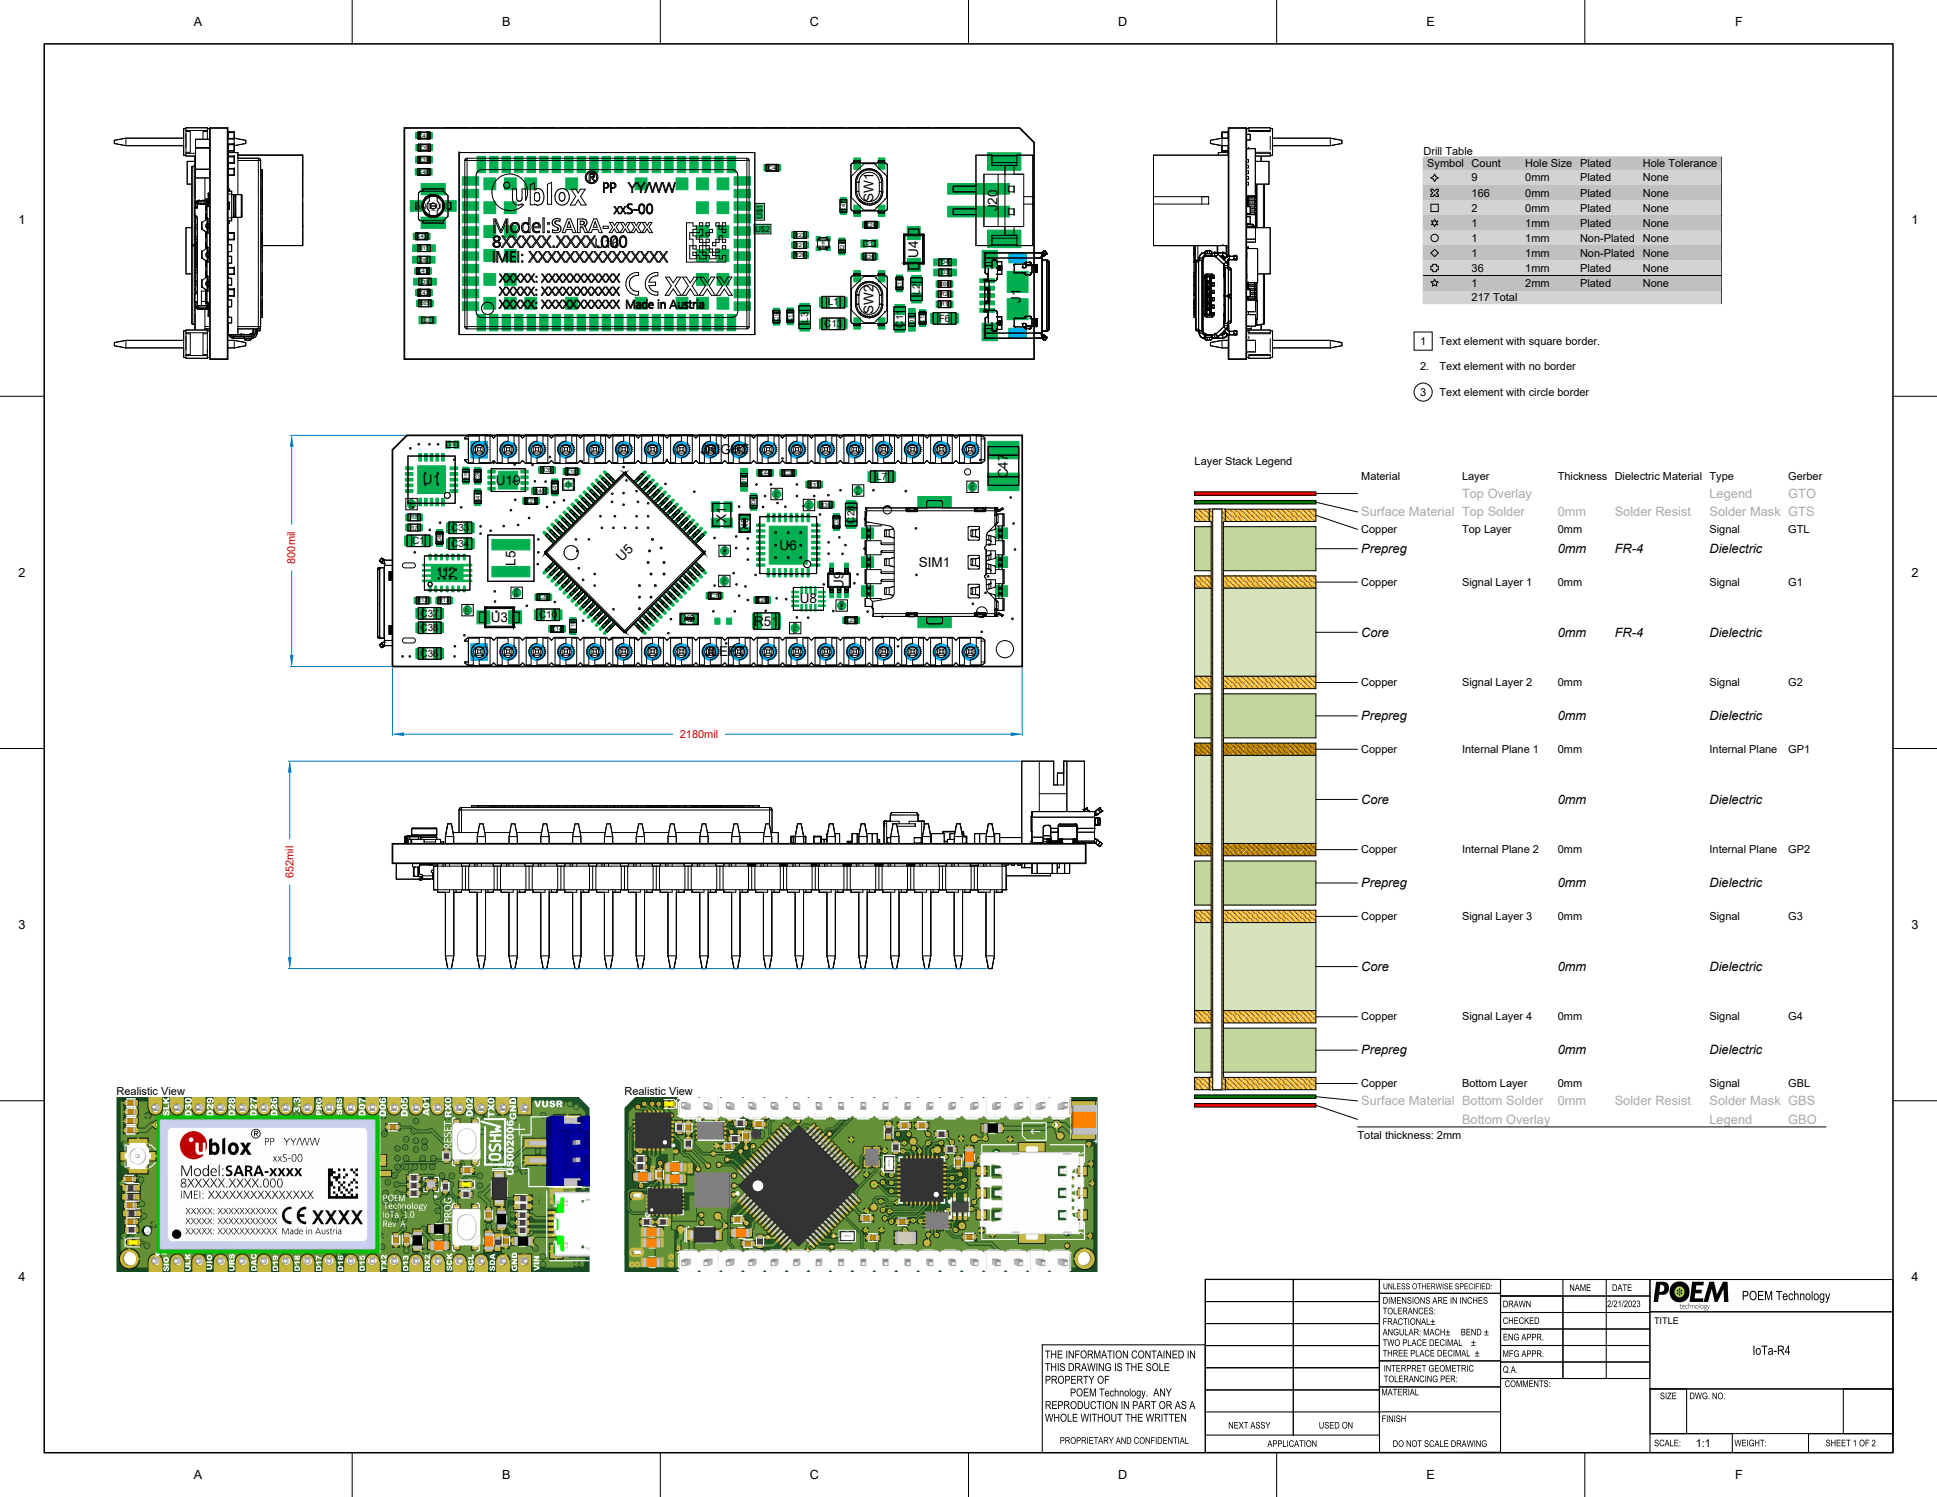
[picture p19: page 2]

2. Text element with no border

3 Text element with circle border

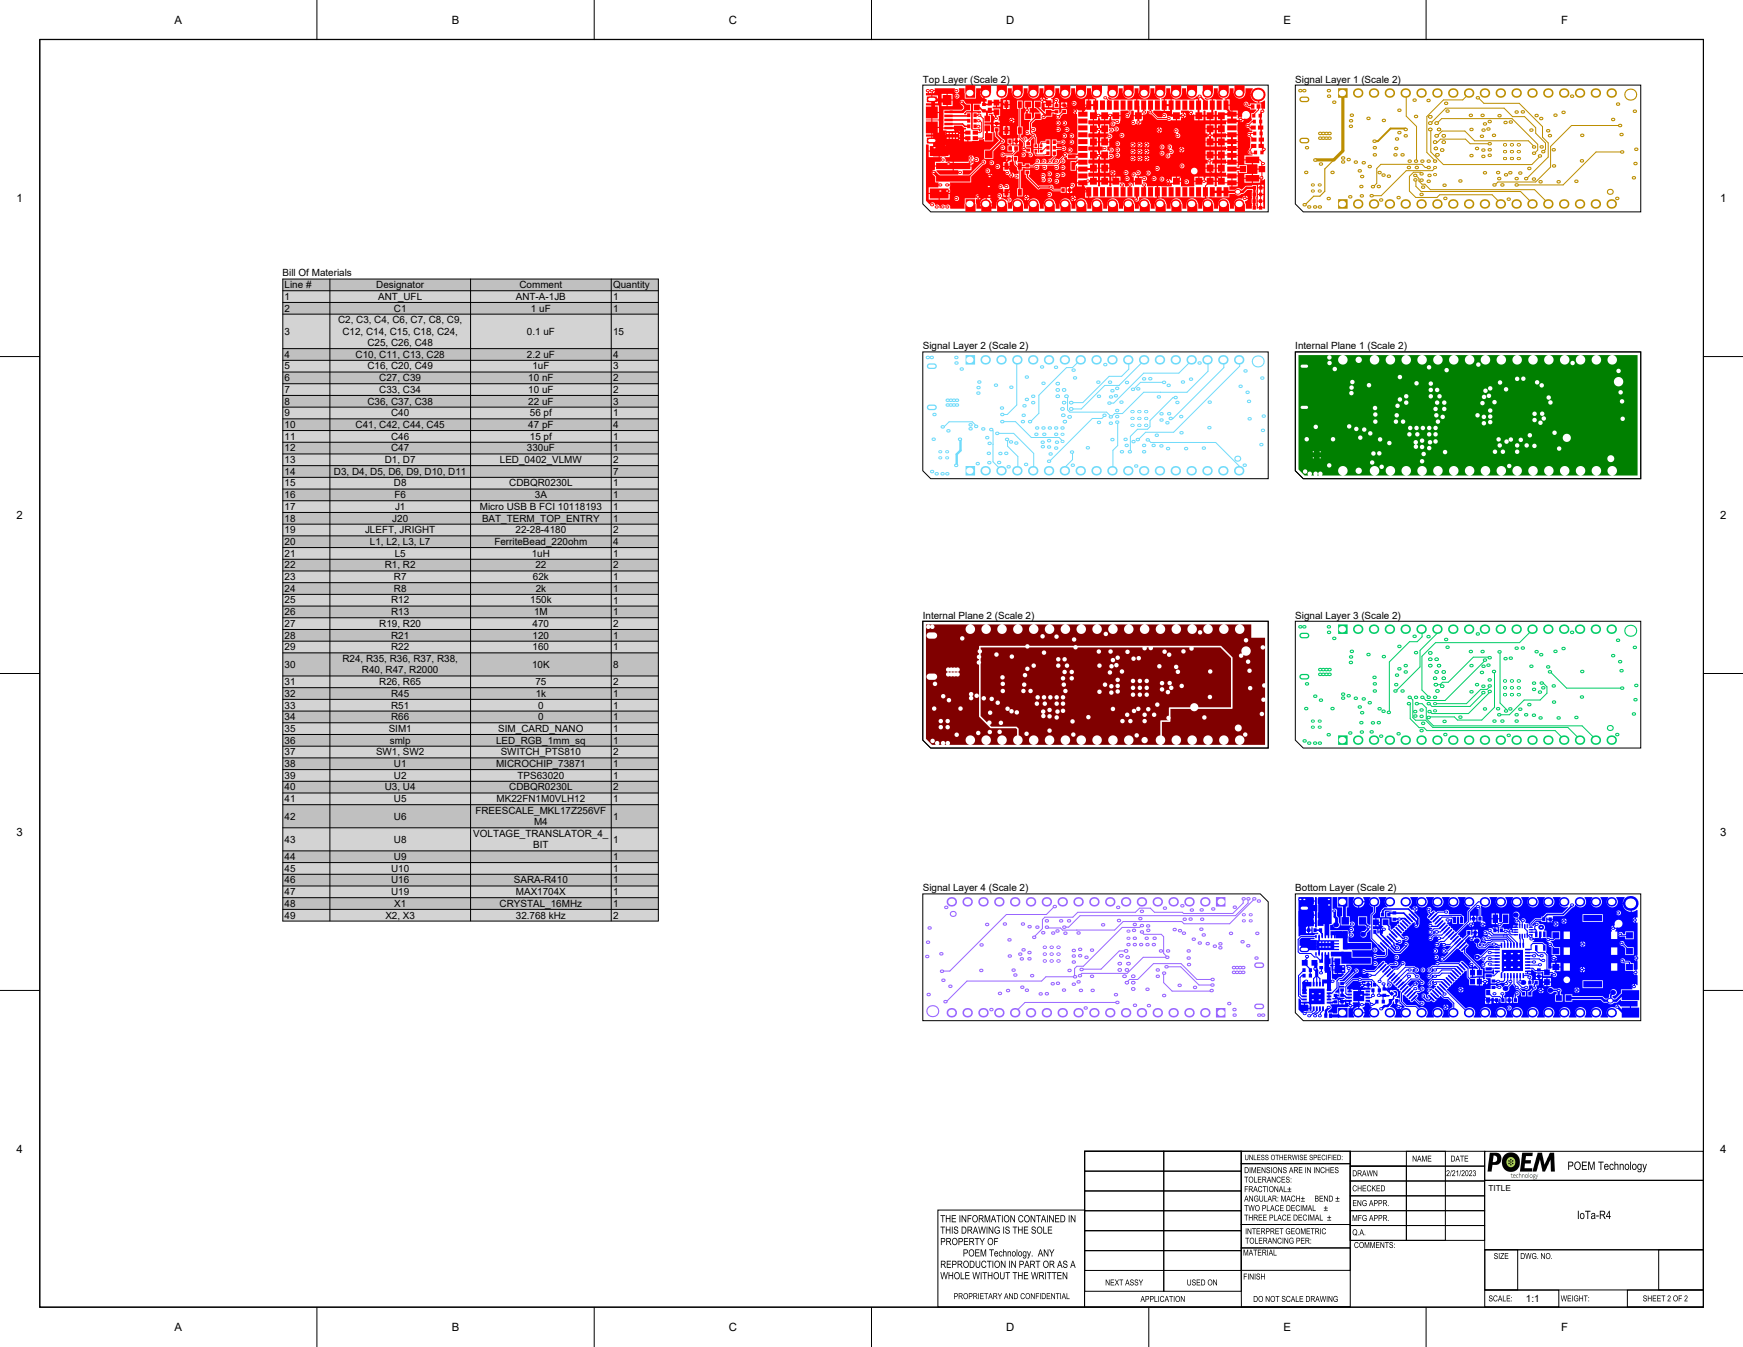
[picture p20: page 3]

Line # 123456789 | C2, C3, C4, C6, C7, C8, C9, C12, C14, C15, C18, C24, C25, C26, C48 | 0.1 uF

Designator | Comment
ANT_UFL | ANT-A-1JB | Quantity 11

19 | JLEFT, JRIGHT | 22-28-4180 | 154322314112711112412111121182111112112111111112

C10, C11, C13, C28 | 2.2 uF
C16, C20, C49 | 1uF
C27, C39 | 10 nF
C33, C34 | 10 uF
C36, C37, C38 | 22 uF
C40 | 56 pf

10 | C41, C42, C44, C45 | 47 pF
11 | C46 | 15 pf
12 | C47 | 330uF
13 | D1, D7 | LED_0402_VLMW
14 | D3, D4, D5, D6, D9, D10, D11
15 | D8 | CDBQR0230L
16 | F6 | 3A
17 | J1 | Micro USB B FCI 10118193
18 | J20 | BAT_TERM_TOP_ENTRY

20 | L1, L2, L3, L7 | FerriteBead_220ohm
21 | L5 | 1uH
22 | R1, R2 | 22
23 | R7 | 62k
24 | R8 | 2k
25 | R12 | 150k
26 | R13 | 1M
27 | R19, R20 | 470
28 | R21 | 120
29 | R22 | 160
30 | R24, R35, R36, R37, R38, R40, R47, R2000 | 10K

31 | R26, R65 | 75
32 | R45 | 1k00
33 | R51
34 | R66
35 | SIM1 | SIM_CARD_NANO
36 | smlp | LED_RGB_1mm_sq
37 | SW1, SW2 | SWITCH_PTS810
38 | U1 | MICROCHIP_73871
39 | U2 | TPS63020
40 | U3, U4 | CDBQR0230L
41 | U5 | MK22FN1M0VLH12
42 | U6 | FREESCALE_MKL17Z256VF M4

43 | U8 | VOLTAGE_TRANSLATOR_4_ BIT

44 | U9
45 | U10
46 | U16 | SARA-R410
47 | U19 | MAX1704X
48 | X1 | CRYSTAL_16MHz
49 | X2, X3 | 32.768 kHz

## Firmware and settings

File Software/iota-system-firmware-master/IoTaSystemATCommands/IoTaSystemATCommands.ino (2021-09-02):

/*
  IoTaSystemATCommands.ino - Main system firmware

  https://poemtechnology.com

  Copyright (c) 2017 Konekt, Inc.  All rights reserved.

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
  You should have received a copy of the GNU Lesser General Public
  License along with this library; if not, write to the Free Software
  Foundation, Inc., 51 Franklin St, Fifth Floor, Boston, MA  02110-1301  USA
*/
#include <HologramSystem.h>

#define HOLO_REV 3

#define MAX_COMMAND_SIZE 256
#define MAX_MESSAGE_SIZE 4*1024
#define MAX_TOPICS 10
#define MAX_TOPIC_SIZE 63
#define MAX_READ_SIZE 64

typedef enum {
    MS_STARTUP,
    MS_RUN,
    MS_PASSTHROUGH,
}modem_state;

modem_state state;

uint8_t read_buffer[MAX_READ_SIZE];

sms_event sms;

uint8_t ipc_cmd_buf[MAX_COMMAND_SIZE];
uint8_t ipc_msg_buf[MAX_MESSAGE_SIZE];
char ipc_topics[MAX_TOPICS][MAX_TOPIC_SIZE + 1];
uint32_t ipc_topic_count = 0;
uint32_t ipc_msg_len = 0;
uint32_t ipc_cmd_len = 0;
const char* ipc_topic_list[] =
{ &ipc_topics[0][0], &ipc_topics[1][0], &ipc_topics[2][0],
 &ipc_topics[3][0], &ipc_topics[4][0], &ipc_topics[5][0],
 &ipc_topics[6][0], &ipc_topics[7][0], &ipc_topics[7][0],
 &ipc_topics[8][0], &ipc_topics[9][0] };

int getOldestSMS(sms_event& oldest) {
    if (ublox.getNumSMS() == 0) return 0;

    int index_oldest = 0;
    for (int i = 1; i <= ublox.getSlotsSMS(); i++) {
        if (ublox.readSMS(i, oldest)) {
            index_oldest = i;
            //      Serial.print("+DEBUG: found oldest ");
            //      Serial.print(index_oldest);
            //      Serial.print(" @ ");
            //      Serial.println(Cloud.getSecondsUTC(oldest.timestamp));
            break;
        }
    }
    if (index_oldest == 0) return 0;

    uint32_t numsms = ublox.getNumSMS();
    if (numsms == 1) return index_oldest;

    uint32_t numcomp = 1;
    static sms_event current;
    uint32_t seconds_oldest = Cloud.getSecondsUTC(oldest.timestamp);

    for (int i = index_oldest + 1; i <= ublox.getSlotsSMS() && numcomp < numsms; i++) {
        if (ublox.readSMS(i, current)) {
            numcomp++;
            uint32_t seconds_current = Cloud.getSecondsUTC(current.timestamp);
            if (seconds_current < seconds_oldest) {
                seconds_oldest = seconds_current;
                index_oldest = i;
                memcpy(&oldest, &current, sizeof(sms_event));
            }
        }
        if (numsms != (uint32_t)ublox.getNumSMS()) {
            //restart the loop because we got a new SMS
            //and it could be in any memory location
            i = 0;
            numcomp = 0;
            numsms = ublox.getNumSMS();
        }
    }
    return index_oldest;

}

void sendNextSMS() {
    rtc_datetime_t sms_dt;

    int index = getOldestSMS(sms);
    if (index > 0) {
        OK();
        if (Cloud.checkOTA(index, sms)) {
            return;
        }

        if (Cloud.convertToLocalTime(sms_dt, sms.timestamp)) {
            ublox.deleteSMS(index);

            Serial.print("+HHSMSCTX: \"+");
            Serial.print(sms.sender);
            Serial.print("\",\"");
            Serial.print(sms_dt);
            Serial.print("\",");
            Serial.println(strlen(sms.message));
            Serial.println(sms.message);
            return;
        }
    }

    ERROR();
}

void handle_event(ublox_event_id id, const ublox_event_content* content) {
    switch (id) {
    case UBLOX_EVENT_SMS_RECEIVED:
        Serial.print("+HHSMSRX: ");
        Serial.println(ublox.getNumSMS());
        break;
    case UBLOX_EVENT_SOCKET_ACCEPT:
        Cloud.acknowledgeAccept(content->accept.socket);
        Serial.print("+HHSOCKACCEPT: ");
        Serial.print(content->accept.socket);
        Serial.print(",\"");
        Serial.print(content->accept.remote.host);
        Serial.print("\",");
        Serial.print(content->accept.remote.port);
        Serial.print(",");
        Serial.println(content->accept.listener);
        Serial.println();
        break;
    case UBLOX_EVENT_CONNECTED:
        Serial.println("+HHCONNECTED: 1");
        break;
    case UBLOX_EVENT_FORCED_DISCONNECT:
        Serial.println("+HHCONNECTED: 0");
        break;
    case UBLOX_EVENT_NETWORK_UNREGISTERED:
        Serial.println("+HHREGISTERED: 0");
        break;
    case UBLOX_EVENT_NETWORK_REGISTERED:
        Serial.println("+HHREGISTERED: 1");
        break;
    case UBLOX_EVENT_NETWORK_TIME_UPDATE:
        break;
    case UBLOX_EVENT_LOCATION_UPDATE:
        //+HHLOC: "2011/04/13,09:54:51",45.6334520,13.0618620,49,1
        //convert location timestamp to local time
        rtc_datetime_t loc_dt;
        Cloud.convertToLocalTime(loc_dt, content->location.timestamp);
        Serial.print("+HHLOC: \"");
        Serial.print(loc_dt);
        Serial.print("\",");
        Serial.print(content->location.lat);
        Serial.print(",");
        Serial.print(content->location.lon);
        Serial.print(",");
        Serial.print(content->location.altitude);
        Serial.print(",");
        Serial.println(content->location.uncertainty);
        break;
    case UBLOX_EVENT_NONE:
        break;
    }
}

typedef enum {
    ST_FIND_A,
    ST_FIND_T,
    ST_IN_COMMAND,
    ST_FIND_EQ,
    ST_FIND_SET,
    ST_IN_SET,
    ST_IN_ERROR,
}parse_state;

typedef enum {
    PR_NEXTCHAR,
    PR_COMMAND,
    PR_SET,
    PR_ERROR,
}process_state;

parse_state st = ST_FIND_A;

void ERROR() {
    if (Serial.available() > 1) {
        Serial.flush();
    }
    else {
    }
    Serial.println("ERROR");
}

void OK() {
    if (Serial.available() > 1) {
        Serial.flush();
        Serial.println("ERROR");
    }
    else {
        Serial.println("OK");
    }
}

void respond(const char* cmd, int value) {
    Serial.print(cmd);
    Serial.print(": ");
    Serial.println(value);
    Serial.println();
    OK();
}

void processQuery(const char* query) {
    if (strcmp(query, "+HOLO") == 0) {
        respond(query, HOLO_REV);
    }
    else if (strcmp(query, "+HSMS") == 0) {
        respond(query, ublox.isNetworkTimeAvailable() ? ublox.getNumSMS() : 0);
    }
    else if (strcmp(query, "+HCHARGE") == 0) {
        respond(query, (int)System.chargeState());
    }
    else {
        const char* r = ublox.query(query);
        if (r == NULL) {
            ERROR();
        }
        else {
            if (strlen(r) > 0) {
                Serial.println(r);
                Serial.println();
            }
            OK();
        }
    }
}

void processCommand(const char* cmd) {
    if (strcmp(cmd, "") == 0) {
        OK();
    }
    else if (strcmp(cmd, "+HMRST") == 0) {
        ipc_topic_count = 0;
        ipc_msg_len = 0;
        OK();
    }
    else if (strcmp(cmd, "+HDEBUGTIMEOUT") == 0) {

    }
    else if (strcmp(cmd, "+HSQ") == 0) {
        volatile uint8_t* p = 0;
        p[0] = strlen(cmd);
        respond(cmd, p[0]);
    }
    else if (strcmp(cmd, "+HCONSTATUS") == 0) {
        respond(cmd, ublox.getConnectionStatus());
    }
    else if (strcmp(cmd, "+HCONNECT") == 0) {
        ublox.powerUp();
        OK();
    }
    else if (strcmp(cmd, "+HDISCONNECT") == 0) {
        OK();
        ublox.powerDown();
    }
    else if (strcmp(cmd, "+HSHUTDOWN") == 0) {
        ublox.powerDown();
        OK();
        Serial.waitToEmpty();
        Serial.end();
        SerialUBlox.end();
        pinMode(USR_TX_TO_SYS_RX, INPUT_PULLDOWN);
        System.shutdown();
        ublox.powerUp();
        restart();
    }
    else if (strcmp(cmd, "+HMSEND") == 0) {
        if (ipc_msg_len > 0) {
            if (Cloud.sendMessage(ipc_msg_buf, ipc_msg_len, ipc_topic_list, ipc_topic_count)) {
                ipc_msg_buf[ipc_msg_len] = 0;
                OK();
            }
            else {
                ERROR();
            }
            ipc_msg_len = 0;
            ipc_topic_count = 0;
        }
        else {
            ERROR();
        }
    }
    else if (strcmp(cmd, "+HSMSRD") == 0) {
        sendNextSMS();
    }
    else if (strcmp(cmd, "+HMODEMRESET") == 0) {
        ublox.powerUp();
        OK();
    }
    else {
        const char* r = ublox.command(cmd);
        if (r == NULL) {
            ERROR();
        }
        else {
            if (strlen(r) > 0) {
                Serial.println(r);
                Serial.println();
            }
            OK();
        }
    }
}

void processSet(const char* cmd, const char* set) {
    if (strcmp(cmd, "+HTAG") == 0 || strcmp(cmd, "+HTOPIC") == 0) {
        if (ipc_topic_count < MAX_TOPIC_SIZE && strlen(set) <= MAX_TOPIC_SIZE) {
            strcpy(ipc_topics[ipc_topic_count++], set);
            OK();
        }
        else {
            ERROR();
        }
    }
    else if (strcmp(cmd, "+HMWRITE") == 0) {
        //AT+HMWRITE=<len>\r\n
        //@
        //<data>
        int wrlen = 0;
        int wrover = 0;
        if (sscanf(set, "%d", &wrlen) == 1) {
            if (wrlen > 128) {
                ERROR();
            }
            else {
                if (wrlen + ipc_msg_len > MAX_MESSAGE_SIZE)
                {
                    wrover = ipc_msg_len + wrlen - MAX_MESSAGE_SIZE;
                    wrlen -= wrover;
                }
                System.snooze(2);
                Serial.flush();
                Serial.write('@');
                int towr = wrlen;
                while (towr) {
                    if (Serial.available()) {
                        ipc_msg_buf[ipc_msg_len++] = Serial.read();
                        towr--;
                    }
                }
                while (wrover) {
                    if (Serial.available()) {
                        Serial.read();
                        wrover--;
                    }
                }
                respond(cmd, wrlen);
                ipc_msg_buf[ipc_msg_len] = 0;
            }
        }
        else {
            ERROR();
        }
    }
    else if (strcmp(cmd, "+HSYS") == 0) {
        bool boot = true;
        if (strcmp(set, "1") == 0) {
            boot = true;
        }
        else if (strcmp(set, "2") == 0) {
            boot = false;
        }
        else {
            ERROR();
            return;
        }

        Serial.print(cmd);
        Serial.print(": ");
        Serial.print(set);
        Serial.print(",\"");
        if (boot) {
            Serial.print(System.bootVersion());
        }
        else {
            Serial.print(FIRMWARE_VERSION_STRING);
        }
        Serial.println("\"");
        Serial.println();
        OK();
    }
    else if (strcmp(cmd, "+HRGBN") == 0) {
        if (DASH_1_2 && RGB.on(set)) {
            OK();
        }
        else {
            ERROR();
        }
    }
    else if (strcmp(cmd, "+HRGBH") == 0) {
        char* pEnd;
        int value = strtol(set, &pEnd, 16);
        if (!DASH_1_2 || pEnd[0] != 0) {
            ERROR();
        }
        else {
            RGB.on(value);
            OK();
        }
    }
    else if (strcmp(cmd, "+HLED") == 0) {
        if (strcmp("1", set) == 0) {
            System.onLED();
            OK();
        }
        else if (strcmp("0", set) == 0) {
            System.offLED();
            OK();
        }
        else {
            ERROR();
        }
    }
    else if (strcmp(cmd, "+HDEBUGDELAYERR") == 0) {
        System.snooze(atoi(set));
        ERROR();
    }
    else if (strcmp(cmd, "+HDEBUGDELAY") == 0) {
        System.snooze(atoi(set));
        OK();
    }
    else if (strcmp(cmd, "+HLOC") == 0) {
        int timeout, accuracy;
        if (sscanf(set, "%d,%d", &timeout, &accuracy) == 2) {
            if (ublox.getLocation(2, 2, 0, timeout, accuracy)) {
                OK();
            }
            else {
                ERROR();
            }
        }
        else {
            ERROR();
        }
    }
    else if (strcmp(cmd, "+HSOCKLISTEN") == 0) {
        int port;
        if (sscanf(set, "%d", &port) == 1) {
            int socket = Cloud.listen(port);
            if (socket == 0) {
                ERROR();
            }
            else {
                respond(cmd, socket);
            }
        }
        else {
            ERROR();
        }
    }
    else if (strcmp(cmd, "+HSOCKREAD") == 0) {
        int socket, maxlen, timeout, hex;
        if (sscanf(set, "%d,%d,%d,%d", &socket, &maxlen, &timeout, &hex) == 4) {
            if (hex == 1) {
                if (maxlen > MAX_READ_SIZE / 2) maxlen = MAX_READ_SIZE / 2;
            }
            else {
                if (maxlen > MAX_READ_SIZE) maxlen = MAX_READ_SIZE;
            }
            int r = ublox.read(socket, maxlen, read_buffer, timeout, hex == 1);
            if (r == -1) {
                ERROR();
            }
            else {
                Serial.print("+HSOCKREAD: ");
                Serial.print(socket);
                Serial.print(",");
                Serial.print(hex == 1 ? 1 : 0);
                Serial.print(",");
                Serial.print(r);
                Serial.print(",\"");
                if (hex == 1) r *= 2;
                for (int i = 0; i < r; i++)
                    Serial.write(read_buffer[i]);
                Serial.print("\"");
                Serial.println();
                Serial.println();
                OK();
            }
        }
        else {
            ERROR();
        }
    }
    else if (strcmp(cmd, "+HSOCKCLOSE") == 0) {
        int socket;
        if (sscanf(set, "%d", &socket) == 1) {
            ublox.close(socket);
            OK();
        }
        else {
            ERROR();
        }
    }
    else if (strcmp(cmd, "+HPASSTHROUGH") == 0) {
        int value;
        if (sscanf(set, "%d", &value) == 1) {
            OK();
            state = MS_PASSTHROUGH;
        }
        else {
            ERROR();
        }
    }
    else {
        const char* r = ublox.set(cmd, set);
        if (r == NULL) {
            ERROR();
        }
        else {
            if (strlen(r) > 0) {
                Serial.println(r);
                Serial.println();
            }
            OK();
        }
    }
}

void processError(const char* cmd, const char* set) {
    Serial.println("ERROR");
}

void pushChar(uint8_t c)
{
    process_state pr = PR_NEXTCHAR;
    static char* pset = NULL;
    ipc_cmd_buf[ipc_cmd_len] = c;

    switch (st) {
    case ST_FIND_A:
        if (c == 'A' || c == 'a') {
            st = ST_FIND_T;
        }
        else if (c == '\r' || c == '\n' || c == ' ') {
            return; //skip
        }
        else {
            st = ST_IN_ERROR;
        }
        break;
    case ST_FIND_T:
        st = (c == 'T' || c == 't') ? ST_IN_COMMAND : ST_IN_ERROR;
        break;
    case ST_IN_COMMAND:
        if (c == ' ') {
            ipc_cmd_buf[ipc_cmd_len] = 0;
            st = ST_FIND_EQ;
        }
        else if (c == '=') {
            ipc_cmd_buf[ipc_cmd_len] = 0;
            st = ST_FIND_SET;
        }
        else if (c == '\r' || c == '\n') {
            pr = PR_COMMAND;
            ipc_cmd_buf[ipc_cmd_len] = 0;
        }
        else if (c >= 'a' && c <= 'z') {
            ipc_cmd_buf[ipc_cmd_len] -= 32; //capitalize
        }
        break;
    case ST_FIND_EQ:
        if (c == '=') {
            st = ST_FIND_SET;
        }
        else if (c == '\r' || c == '\n') {
            pr = PR_COMMAND;
        }
        else if (c == ' ') {
            return; //skip
        }
        else {
            st = ST_IN_ERROR;
        }
        break;
    case ST_FIND_SET:
        if (c == '\r' || c == '\n') {
            st = ST_IN_ERROR;
        }
        else if (c == ' ') {
            return; //skip
        }
        else {
            pset = (char*)&ipc_cmd_buf[ipc_cmd_len];
            st = ST_IN_SET;
        }
        break;
    case ST_IN_SET:
        if (c == '\r' || c == '\n') {
            ipc_cmd_buf[ipc_cmd_len] = 0;

            //trim trailing ' '
            int z = ipc_cmd_len - 1;
            while (ipc_cmd_buf[z] == ' ') {
                ipc_cmd_buf[z] = 0;
                z--;
            }

            pr = PR_SET;
        }
        break;
    case ST_IN_ERROR:
        if (c == '\r' || c == '\n') {
            pr = PR_ERROR;
        }
    }

    if (pr == PR_NEXTCHAR) {
        ipc_cmd_len++;
    }
    else {
        if (pr == PR_COMMAND) {
            char* pcmd = (char*)(ipc_cmd_buf + 2);
            int len = strlen(pcmd);
            if (len == 0) {
                OK();
                Serial.println("+HDEBUG: AT");
            }
            else if (len > 0 && pcmd[len - 1] == '?') {
                pcmd[len - 1] = 0;
                processQuery(pcmd);
            }
            else {
                processCommand(pcmd);
            }
        }
        else if (pr == PR_SET) {
            processSet((const char*)(ipc_cmd_buf + 2), pset);
        }
        else if (pr == PR_ERROR) {
            processError((const char*)(ipc_cmd_buf + 2), pset);
        }
        ipc_cmd_len = 0;
        pset = NULL;
        st = ST_FIND_A;
    }
}

void chargeStateChanged(CHARGE_STATE cs) {
    Serial.print("+HHCHARGE: ");
    Serial.println((int)cs);
}

CHARGE_STATE updateCharge() {
    static CHARGE_STATE prev = CHARGE_UNKNOWN;
    CHARGE_STATE curr = System.chargeState();
    if (prev != curr) {
        uint32_t start = millis();
        while (millis() - start < 30) {
            for (int i = 0; i < 100; i++) {
                if (System.chargeState() != curr) {
                    return prev;
                }
            }
        }
        prev = curr;
        Serial.print("+HHCHARGE: ");
        Serial.println((int)prev);
    }
    return prev;
}

volatile bool ublox_low = true;
void ublox_on_check() {
    ublox_low = false;
}

void check_ublox() {
    pinMode(SYS_UBLOX_RX, INPUT_PULLDOWN);
    if (digitalRead(SYS_UBLOX_RX) == LOW) {
        attachInterrupt(SYS_UBLOX_RX, ublox_on_check, RISING);
        uint32_t startMillis = millis();
        while (ublox_low && (millis() - startMillis < 100));
        if (ublox_low && digitalRead(SYS_UBLOX_RX) == LOW) {
            //RGB.on(RED);
            System.ubloxReset();
        }
    }
}

void initialize() {
    SerialUBlox.begin(115200);
    Serial.begin(115200);
    Serial.print("+HHOLO: ");
    Serial.println(HOLO_REV);

    Cloud.begin(ublox, AUTH_TOTP, handle_event);
    ublox.begin(Cloud, SerialUBlox);

    SerialUBlox.flush();
    state = MS_RUN;
}

void state_startup() {
    check_ublox();
    initialize();
}

void state_run() {
    bool sleep = true;
    ublox.pollEvents();
    updateCharge();

    while (Serial.available()) {
        sleep = false;
        pushChar(Serial.read());
    }

    if (sleep) {
        Serial.waitToEmpty();
        System.sleep();
    }
}

void setup() {
    updateCharge();
    state = MS_STARTUP;
    ublox_low = true;
}

void restart() {
    wvariant_init();
    initialize();
}

void loop() {
    switch (state) {
    case MS_STARTUP:
        state_startup();
        break;
    case MS_RUN:
        state_run();
        break;
    case MS_PASSTHROUGH:
        while (Serial.available()) {
            SerialUBlox.write(Serial.read());
        }
        while (SerialUBlox.available()) {
            Serial.write(SerialUBlox.read());
        }
        break;
    default:
        break;
    }
}

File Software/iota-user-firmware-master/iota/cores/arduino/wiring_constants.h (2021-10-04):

/*
  wiring_constants.h - Wiring compatibility layer constants and
  function DEFINEs with mods for Konekt Dash and Konekt Dash Pro

  http://konekt.io

  Copyright (c) 2015 Konekt, Inc.  All rights reserved.


  Derived from file with original copyright notice:

  Copyright (c) 2014 Arduino.  All right reserved.

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
  You should have received a copy of the GNU Lesser General Public
  License along with this library; if not, write to the Free Software
  Foundation, Inc., 51 Franklin St, Fifth Floor, Boston, MA  02110-1301  USA
*/

#ifndef _WIRING_CONSTANTS_
#define _WIRING_CONSTANTS_

#ifdef __cplusplus
extern "C"{
#endif // __cplusplus

#define LOW             (0x0)
#define HIGH            (0x1)
#define CHANGE          (0x2)
#define FALLING         (0x3)
#define RISING          (0x4)

#define INPUT           (0x0)
#define OUTPUT          (0x1)
#define INPUT_PULLUP    (0x2)
#define INPUT_PULLDOWN  (0x3)
#define DISABLE         (0x8)

#define PI 3.1415926535897932384626433832795
#define HALF_PI 1.5707963267948966192313216916398
#define TWO_PI 6.283185307179586476925286766559
#define DEG_TO_RAD 0.017453292519943295769236907684886
#define RAD_TO_DEG 57.295779513082320876798154814105
#define EULER 2.718281828459045235360287471352

#define SERIAL  0x0
#define DISPLAY 0x1

enum BitOrder {
	LSBFIRST = 0,
	MSBFIRST = 1
};

typedef struct
{
    uint8_t port;
    uint8_t pin;
    uint8_t wakeup;
    uint8_t adc;
    uint8_t uartMux;
    uint8_t i2cMux;
    uint8_t spiMux;
    uint8_t pwm;
} PinDescription;

#define PORT_A                      (0U)
#define PORT_B                      (1U)
#define PORT_C                      (2U)
#define PORT_D                      (3U)
#define PORT_E                      (4U)

#define MUX_DISABLED                (0U)
#define MUX_ANALOG                  (0U)
#define MUX_GPIO                    (1U)
#define MUX2                        (2U)
#define MUX3                        (3U)
#define MUX4                        (4U)
#define MUX5                        (5U)
#define MUX6                        (6U)
#define MUX7                        (7U)

#define PORT_PULL_DOWN              (0U)
#define PORT_PULL_UP                (1U)

#define SHIFT_ADC_CHAN              (0u)
#define SHIFT_ADC_INST              (5u)
#define SHIFT_ADC_MUX               (6u)
#define MASK_ADC_CHAN               (0x1F)
#define MASK_ADC_INST               (1u)
#define MASK_ADC_MUX                (1u)

#define ADC_GET_CHAN(a)             (((a) >> SHIFT_ADC_CHAN) & MASK_ADC_CHAN)
#define ADC_GET_INST(a)             (((a) >> SHIFT_ADC_INST) & MASK_ADC_INST)
#define ADC_GET_MUX(a)              (((a) >> SHIFT_ADC_MUX) & MASK_ADC_MUX)

#define PINS_PORT(io)               (g_APinDescription[(io)].port)
#define PINS_PIN(io)                (g_APinDescription[(io)].pin)
#define PINS_WAKEUP(io)             (g_APinDescription[(io)].wakeup)
#define PINS_ADC_CHAN(io)           (ADC_GET_CHAN(g_APinDescription[(io)].adc))
#define PINS_ADC_INST(io)           (ADC_GET_INST(g_APinDescription[(io)].adc))
#define PINS_ADC_MUX(io)            (ADC_GET_MUX(g_APinDescription[(io)].adc))
#define PINS_MUX_UART(io)           (g_APinDescription[(io)].uartMux)
#define PINS_MUX_I2C(io)            (g_APinDescription[(io)].i2cMux)
#define PINS_MUX_SPI(io)            (g_APinDescription[(io)].spiMux)
#define PINS_PWM_CHAN(io)           (PWM_GET_CHAN(g_APinDescription[(io)].pwm))
#define PINS_PWM_INST(io)           (PWM_GET_INST(g_APinDescription[(io)].pwm))
#define PINS_PWM_MUX(io)            (PWM_GET_MUX(g_APinDescription[(io)].pwm))
#define PINS_MUX_PWM(io)            (PINS_PWM_MUX(io) == 0 ? MUX4 : MUX3)
#define PINS_PWM_DAC(io)            (PWM_GET_DAC(g_APinDescription[(io)].pwm))

#define PERIPH_PORT_SIZE            0x1000
#define PERIPH_FROM_PORT(port)      (PORT_Type *)(PORTA_BASE+((port)*PERIPH_PORT_SIZE))
#define PERIPH_PORT(io)             PERIPH_FROM_PORT(PINS_PORT(io)) //(PORT_Type *)(PORTA_BASE+(PINS_PORT(io)*PERIPH_PORT_SIZE)) //g_portBase[PINS_PORT(io)]

#define PERIPH_GPIO_SIZE            0x0040
#define PERIPH_GPIO(io)             (GPIO_Type *)(  PTA_BASE+(PINS_PORT(io)*PERIPH_GPIO_SIZE)) //g_gpioBase[PINS_PORT(io)]

#define PORT_SET_MUX(io, mux)       (PORT_WR_PCR_MUX(PERIPH_PORT(io), PINS_PIN(io), (mux)))
#define PORT_SET_MUX_DISABLED(io)   (PORT_SET_MUX((io), MUX_DISABLED))
#define PORT_SET_MUX_ANALOG(io)     (PORT_SET_MUX((io), MUX_ANALOG))
#define PORT_SET_MUX_GPIO(io)       (PORT_SET_MUX((io), MUX_GPIO))
#define PORT_SET_MUX_UART(io)       (PORT_SET_MUX((io), PINS_MUX_UART(io)))
#define PORT_SET_MUX_I2C(io)        (PORT_SET_MUX((io), PINS_MUX_I2C(io)))
#define PORT_SET_MUX_SPI(io)        (PORT_SET_MUX((io), PINS_MUX_SPI(io)))
#define PORT_SET_MUX_PWM(io)        (PORT_SET_MUX((io), PINS_MUX_PWM(io)))

#define GPIO_PIN(io)                ((1U) << (PINS_PIN(io)))
#define GPIO_PIN_DIRECTION(io)      (((GPIO_RD_PDDR(PERIPH_GPIO(io)) & GPIO_PIN(io)) == 0) ? (INPUT) : (OUTPUT))
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

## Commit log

2021-06-21 Rename BOM-PT-IoTa RevE.csv to BOM-IoTa RevE.csv
    [BOM-IoTa RevE.csv]
2021-10-04 Initial commit of POEm Technology IoTa-branded user firmware source code and Arduino package.
2021-10-05 Bug fix: IoTa not recognized in Arduino enviroment board manager. Renamed package JSON file to use "iota" instead of "poemtechnology" and rebuilt package. Modified package creation script to reflect 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
2021-10-05 Bug fix: Arduino environment does not recognize IoTa package. Changed GitHub URL for the ZIP to use the "raw" version which will initiate a download rather than navigate to ZIP file page.
2022-01-21 Delete PT_SAT_Simplex.SchDoc
    Not in the design
    [PT_SAT_Simplex.SchDoc]
2023-02-21 Add files via upload
    Page1: Schematic
    Page 2: Assembly, Drill, Layer Stackup, 3D
    Page 3: BOM, Layers
2023-02-21 Delete BOM-IoTa RevE.csv
    New numbering
    IoTa 1.0 Rev A
    [BOM-IoTa RevE.csv]
2023-02-23 Ver 1.0 RevA
    [IoTa_1_0.SchDoc]
2023-02-23 Ver 1.0 Rev A
    [HOL-Dash_1_2.SchDoc]
